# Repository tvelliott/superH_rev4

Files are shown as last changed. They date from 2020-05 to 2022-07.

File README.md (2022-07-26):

<html>
<b>High-performance narrow-band receiver hardware.</b>
<BR>
<BR><B>SuperH_rev4</B>
<BR>
<p>
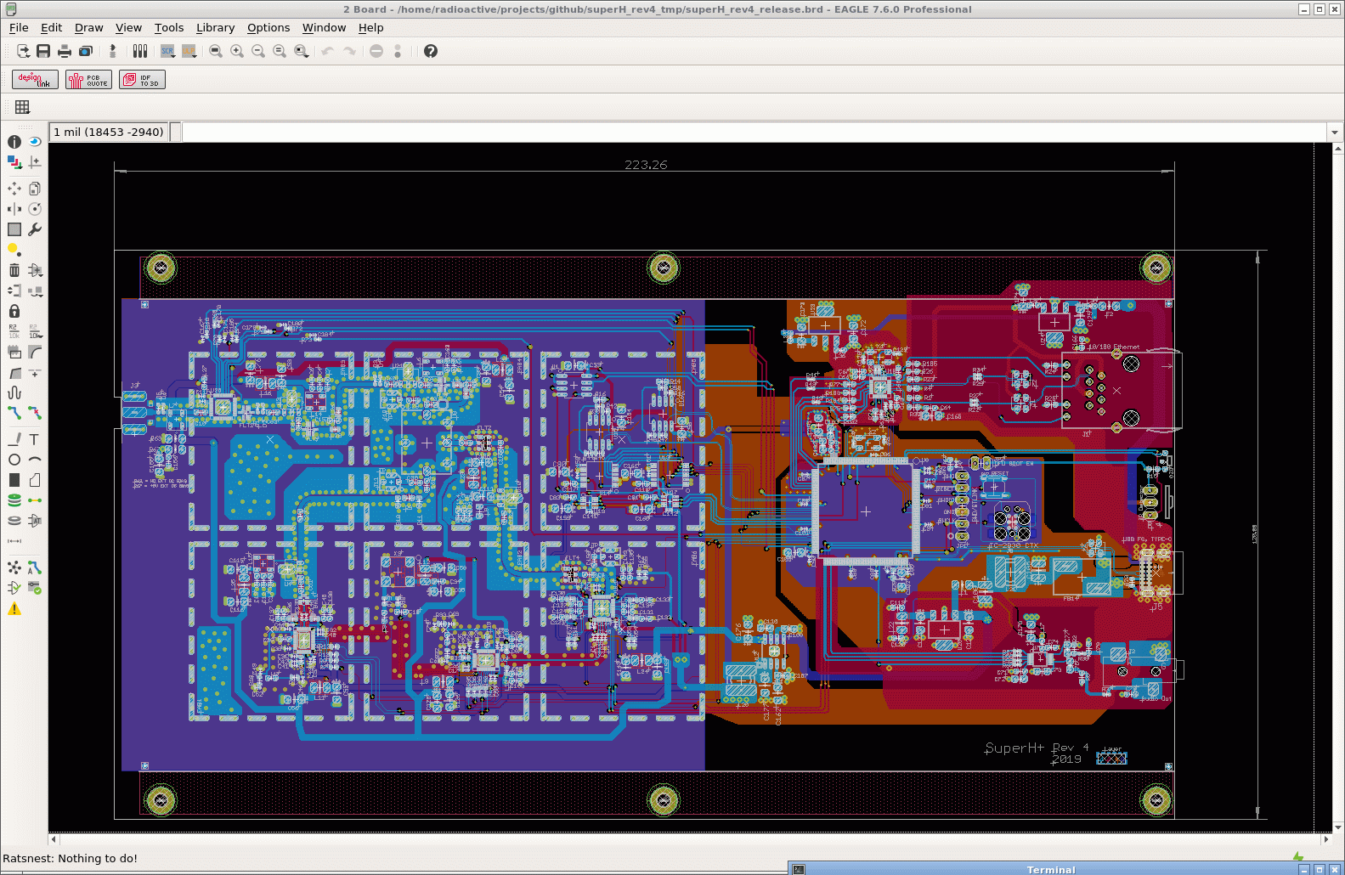
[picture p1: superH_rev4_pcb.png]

<BR>
<BR>
<BR>

<BR>To compile:
<BR>install the gcc arm toolchain version gcc-arm-none-eabi-7-2018-q2-update/
<BR>https://developer.arm.com/tools-and-software/open-source-software/developer-tools/gnu-toolchain/gnu-rm/downloads/7-2018-q2-update
<BR>
<BR>In the firmware directory, create a symbolic link to the toolchain:
<BR>e.g. ln -s ../gcc-arm-none-eabi-7-2018-q2-update arm-toolchain
<BR>Then type 'make' 
<BR><BR>
The firmware can decode the follow protocols in stand-alone mode (NO PC):
<PRE>
Available SuperH+ built-in/stand-alone demod/decoders
------------------
FM Analog narrow/med/wide (mode fm)
AM Analog narrow/med/wide (mode am)
IQ 16-bit over UDP (mode iq) + GNURadio Driver
P25P1 Voice + Trunking Control Channel (mode p25)
DMR Voice + ConnectPlus Trunking Control Channel (mode dmr)
ADSB Mode-S - Console output (mode adsb)   This mode uses 2 separate ADCs in single ended mode with 2 Msps / 8-bit.
ACARS - Console output (mode acars)
FLEX-4FSK-1600 - Console output (mode pagers, fm)
POCSAG 1200 - Console output (mode pagers, fm)
</PRE>
<BR>
<BR>

1st IF is 1.5 GHz  (high IF like a typical spectrum analyzer)
<BR><BR>
Baseband filters are 10 - 150 kHz in 16 steps.  70dB adjacent rejection,  100+ dB alternate rejection.
<BR><BR>NCO based final tuning.
<BR><BR>20dB pre-LNA step-attenuator front-end (controlled by AGC)
<BR><BR>AGC + DSP extends dynamic range to over 150dB.
<BR><BR>ACARS receives long messages >350 miles away with an indoor antenna and 0 bit errors.
<BR><BR>DC coupling and extremely stable TCXO makes sub-Hz demodulation with software-based DC offset correction possible
<BR><BR>I/Q ADCs SNR is >= 82 dB in 16-bit differential mode of operation (10-150 kHz baseband filter mode).   

<BR>
<BR>
<a href="https://github.com/tvelliott/superH_rev4/blob/master/audio_samples/superH_fm_radio_dynamics_silence_demo.wav">superH_fm_radio_dynamics_silence_demo.wav (recorded off air)</a>
<BR>
<BR>
superH FM demod demonstration   
https://youtu.be/HBXcUFW8yaA  
<BR><BR>
P25P1 demo
https://youtu.be/G3MCHvNcKHg
<BR><BR>
superH gqrx / 40-meter / AM demo
https://youtu.be/u9L5sJRPFiQ
<BR><BR>
Local ham radio repeater VHF
https://youtu.be/9KYXXc-55yA
<BR><BR>
SuperH+ receiving ADSB
https://youtu.be/LvIR2hlR7_A
<BR><BR>
<BR>
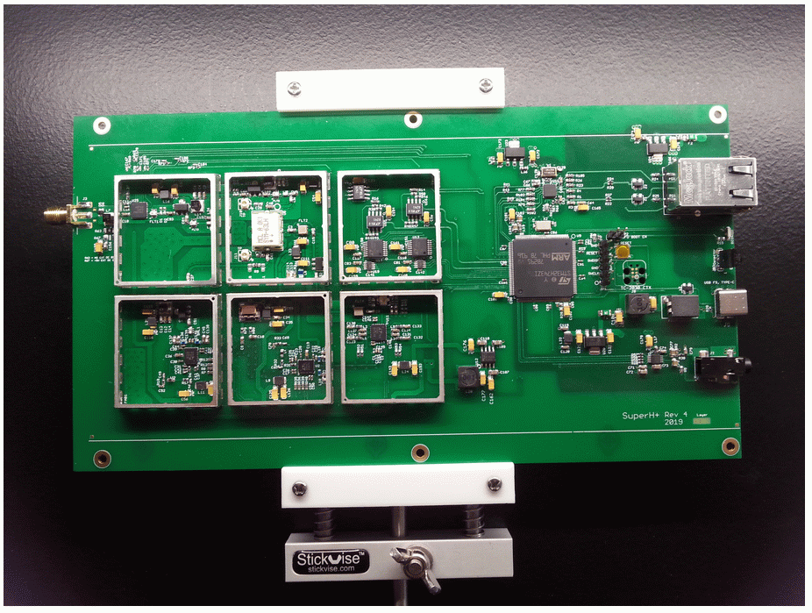
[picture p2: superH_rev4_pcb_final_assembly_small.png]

<BR>
</html>

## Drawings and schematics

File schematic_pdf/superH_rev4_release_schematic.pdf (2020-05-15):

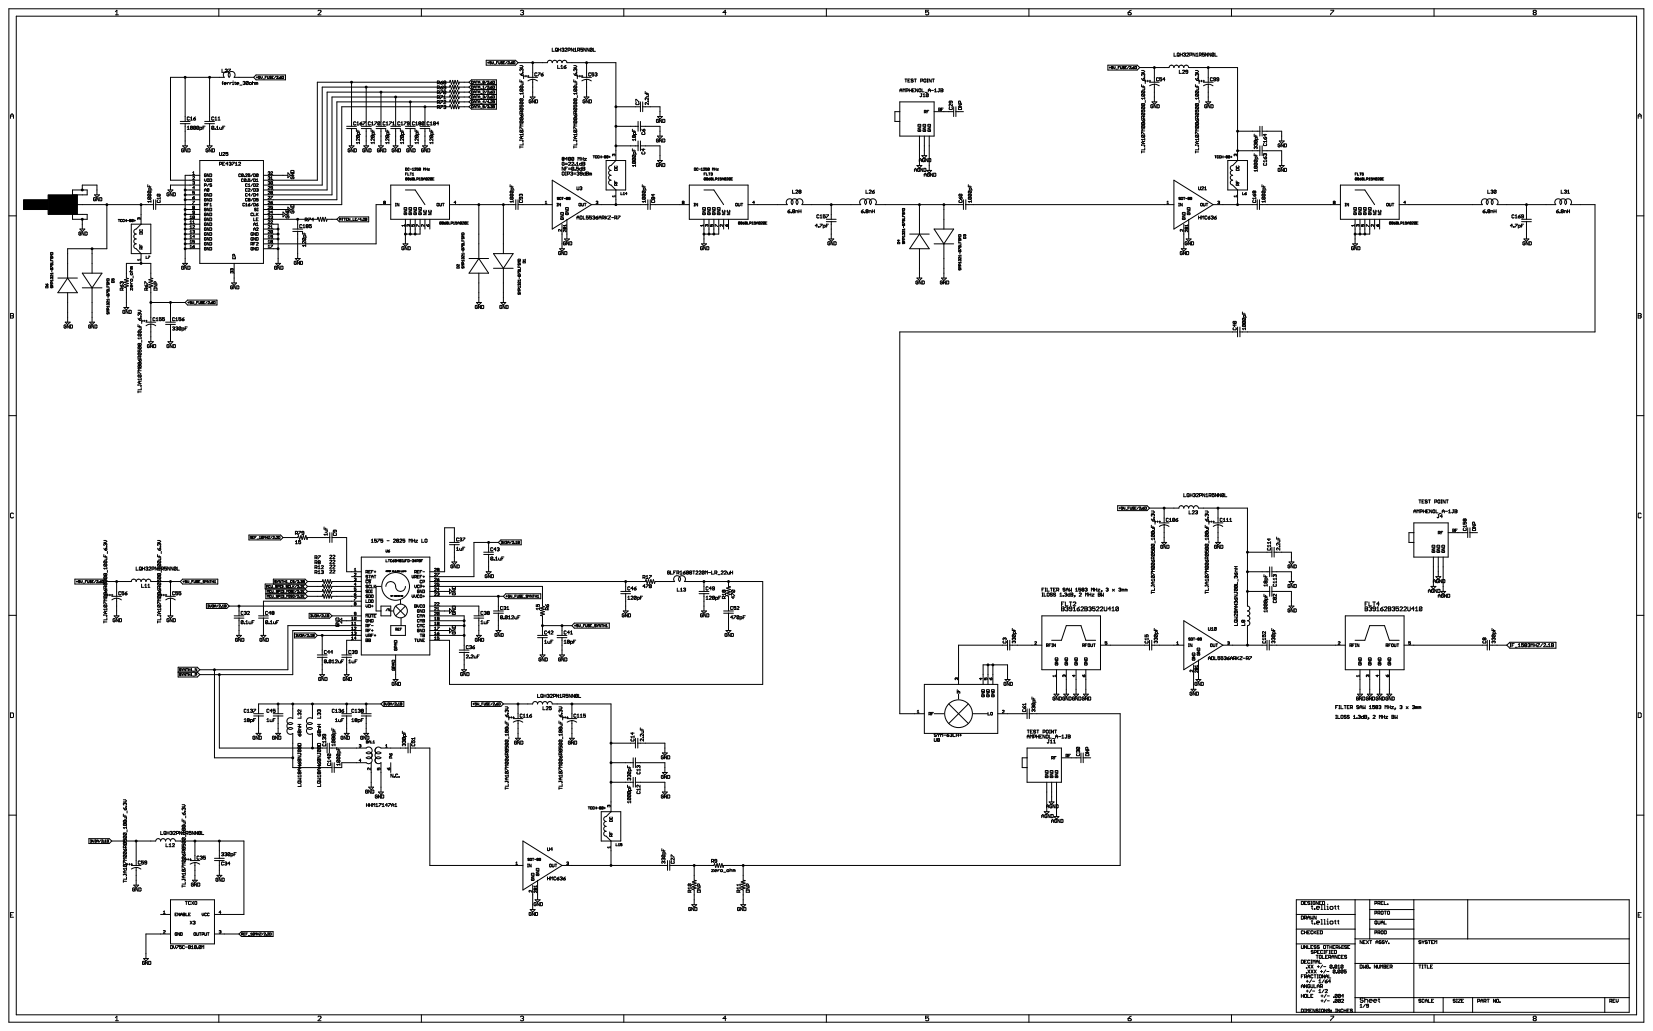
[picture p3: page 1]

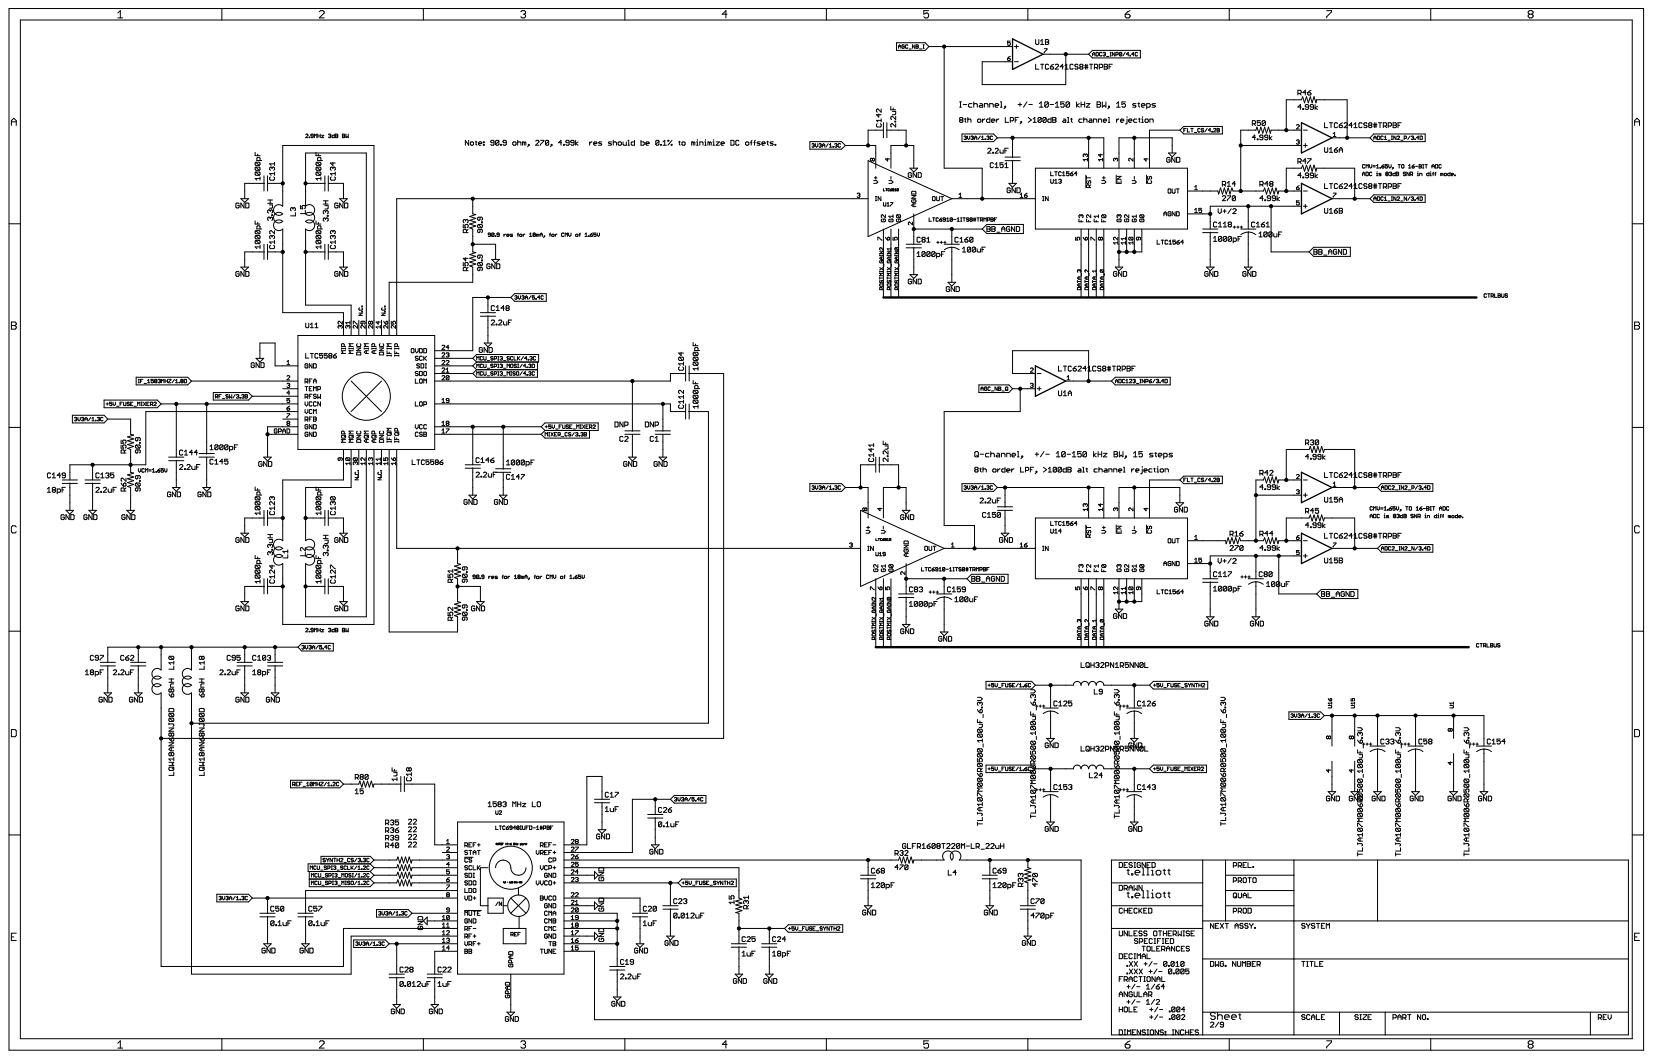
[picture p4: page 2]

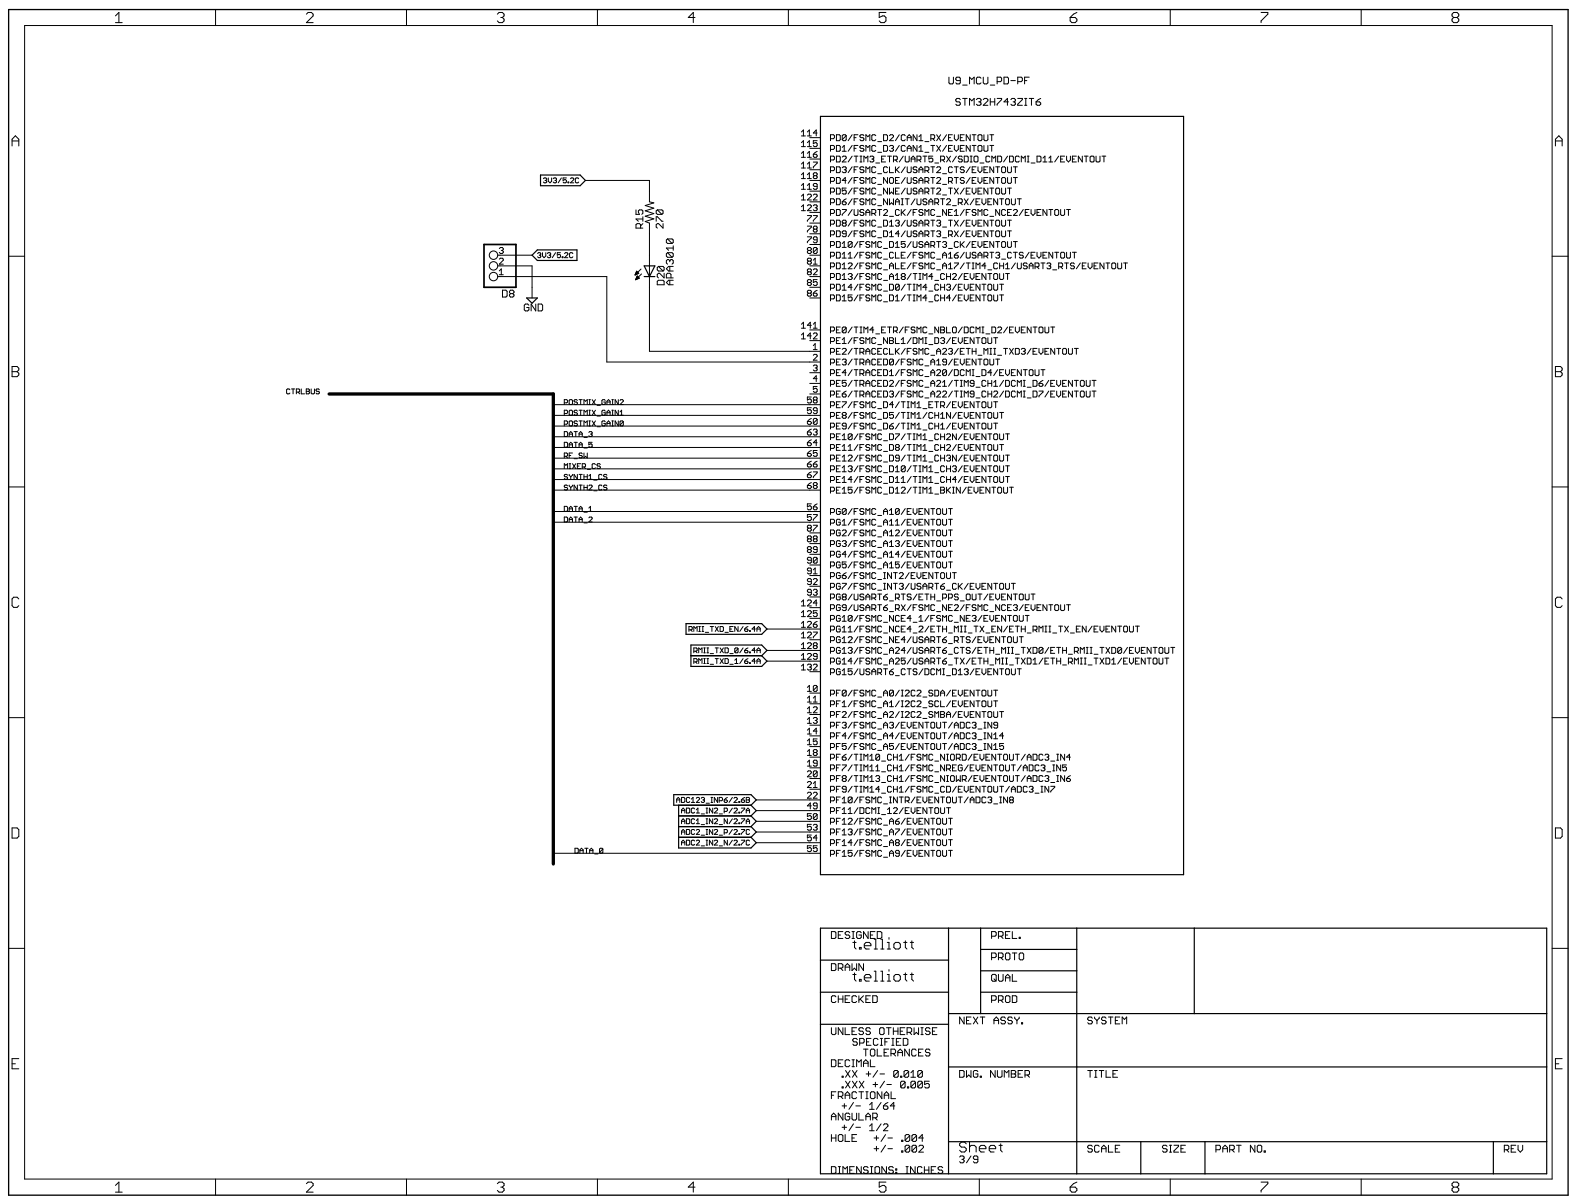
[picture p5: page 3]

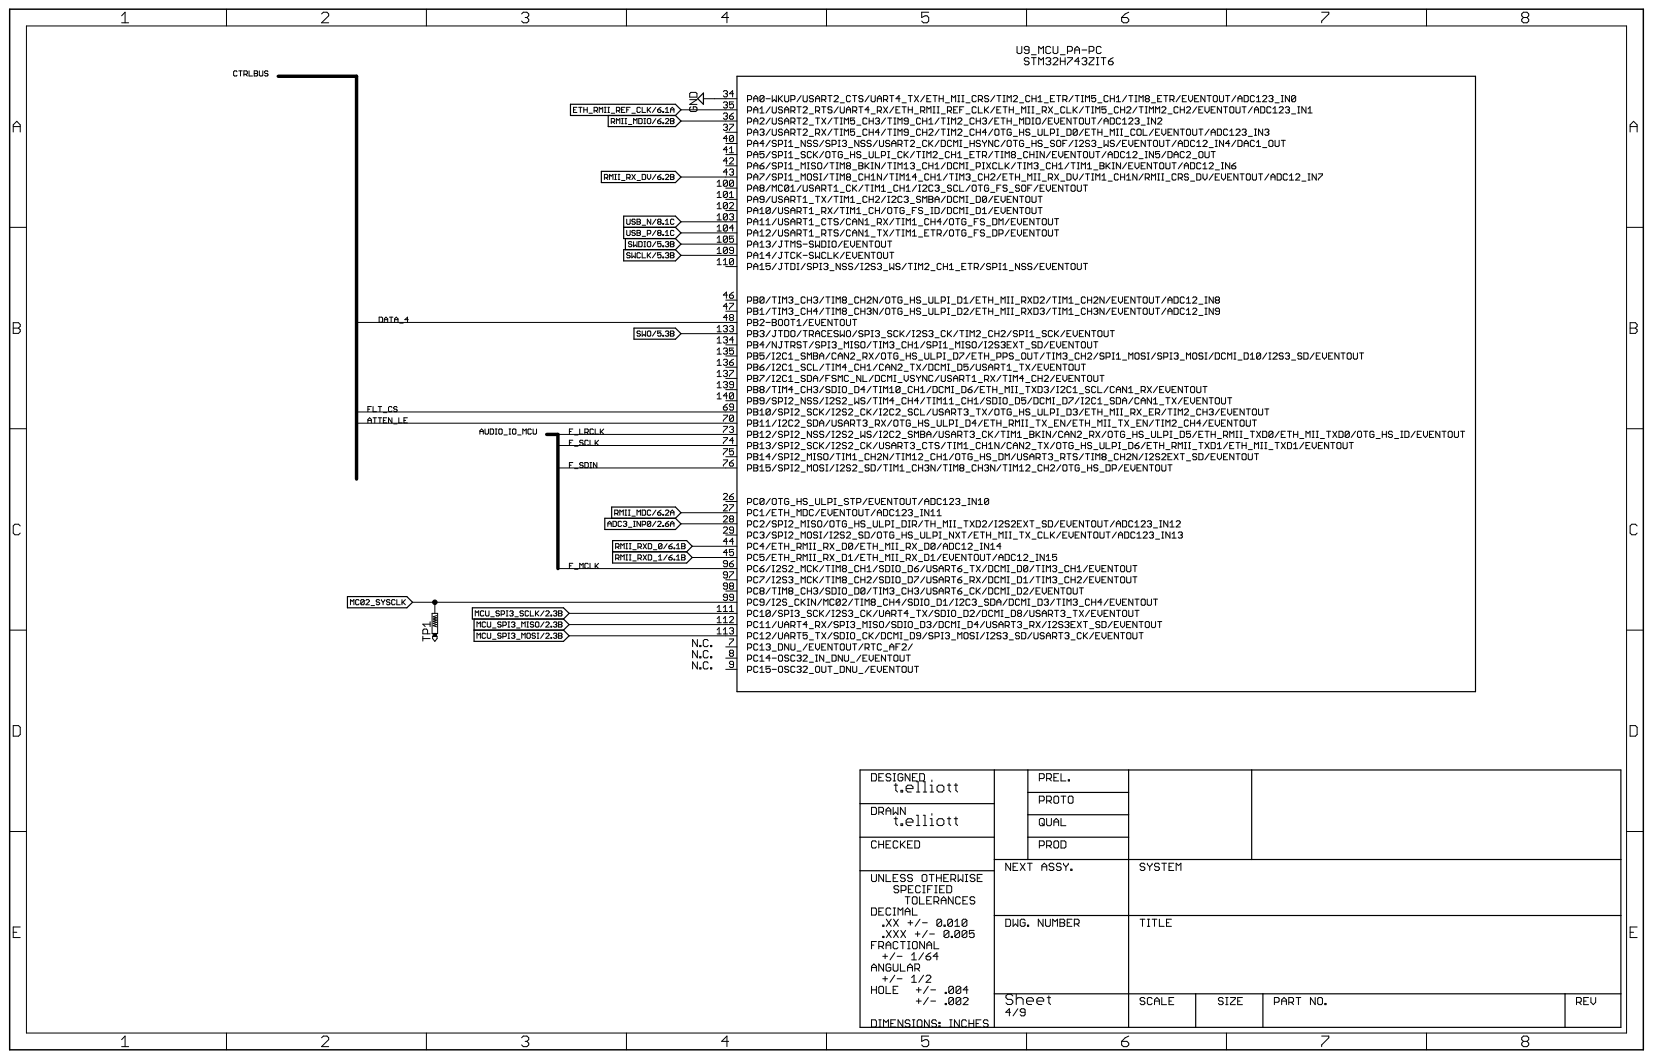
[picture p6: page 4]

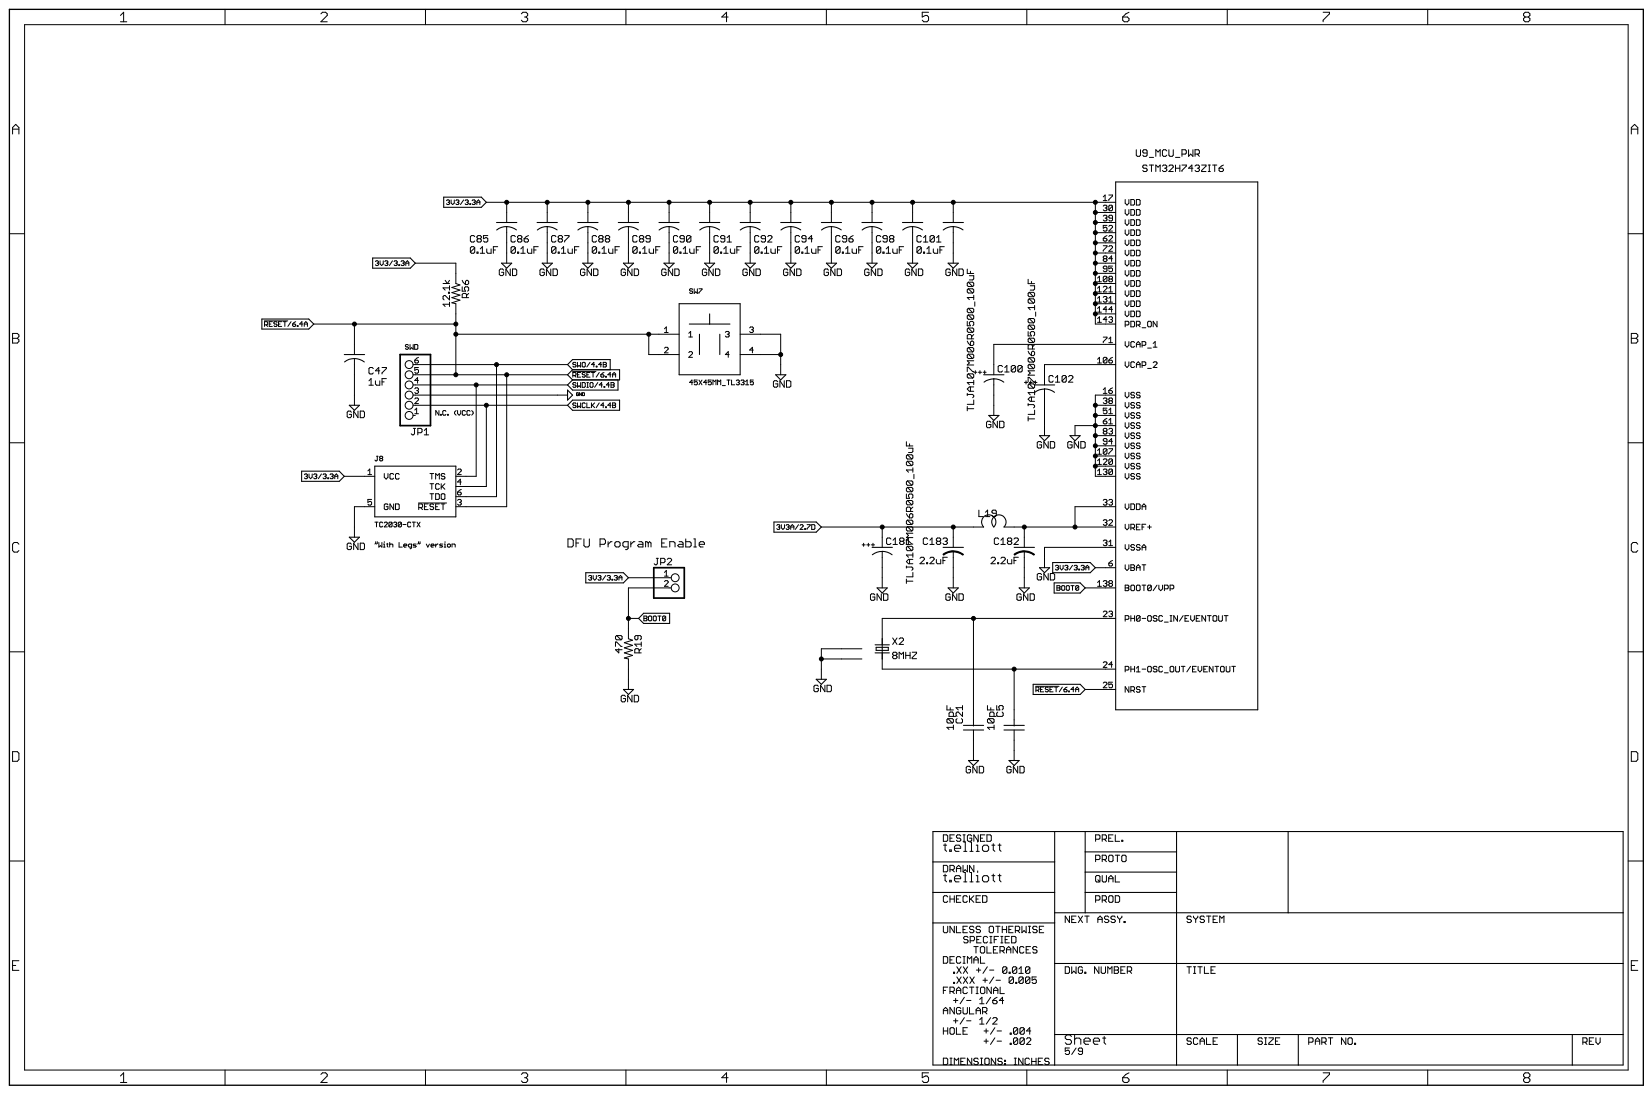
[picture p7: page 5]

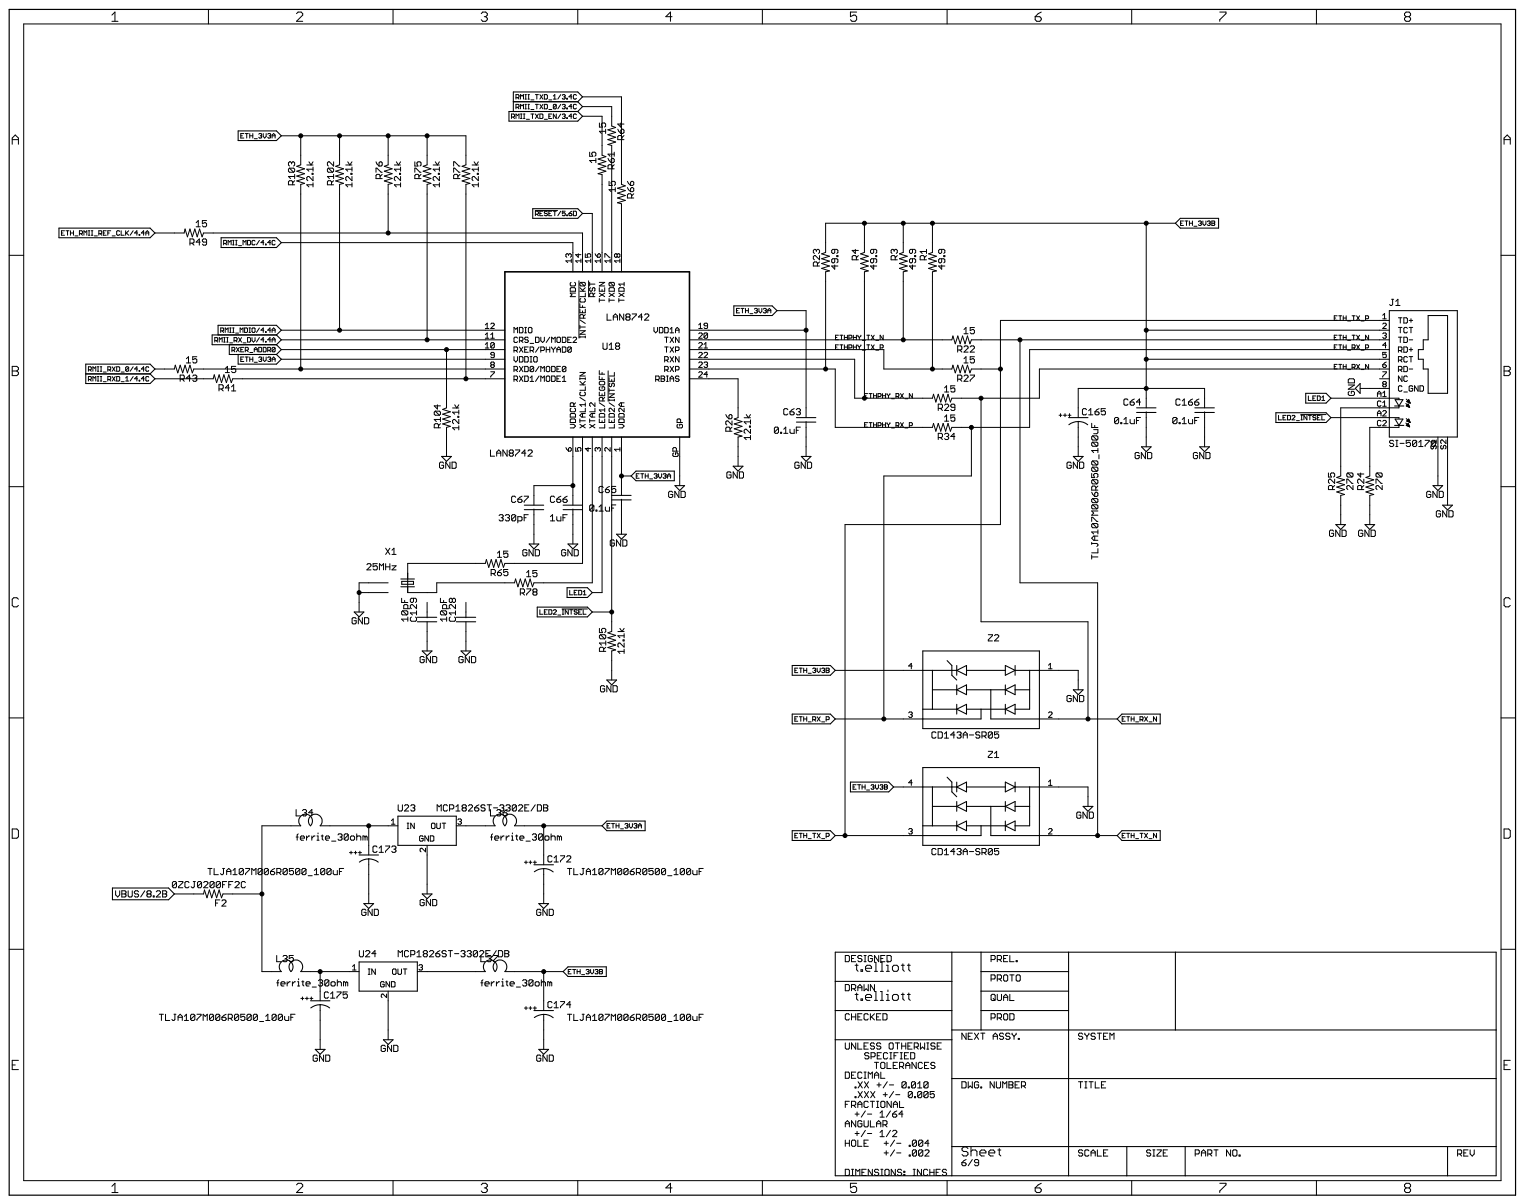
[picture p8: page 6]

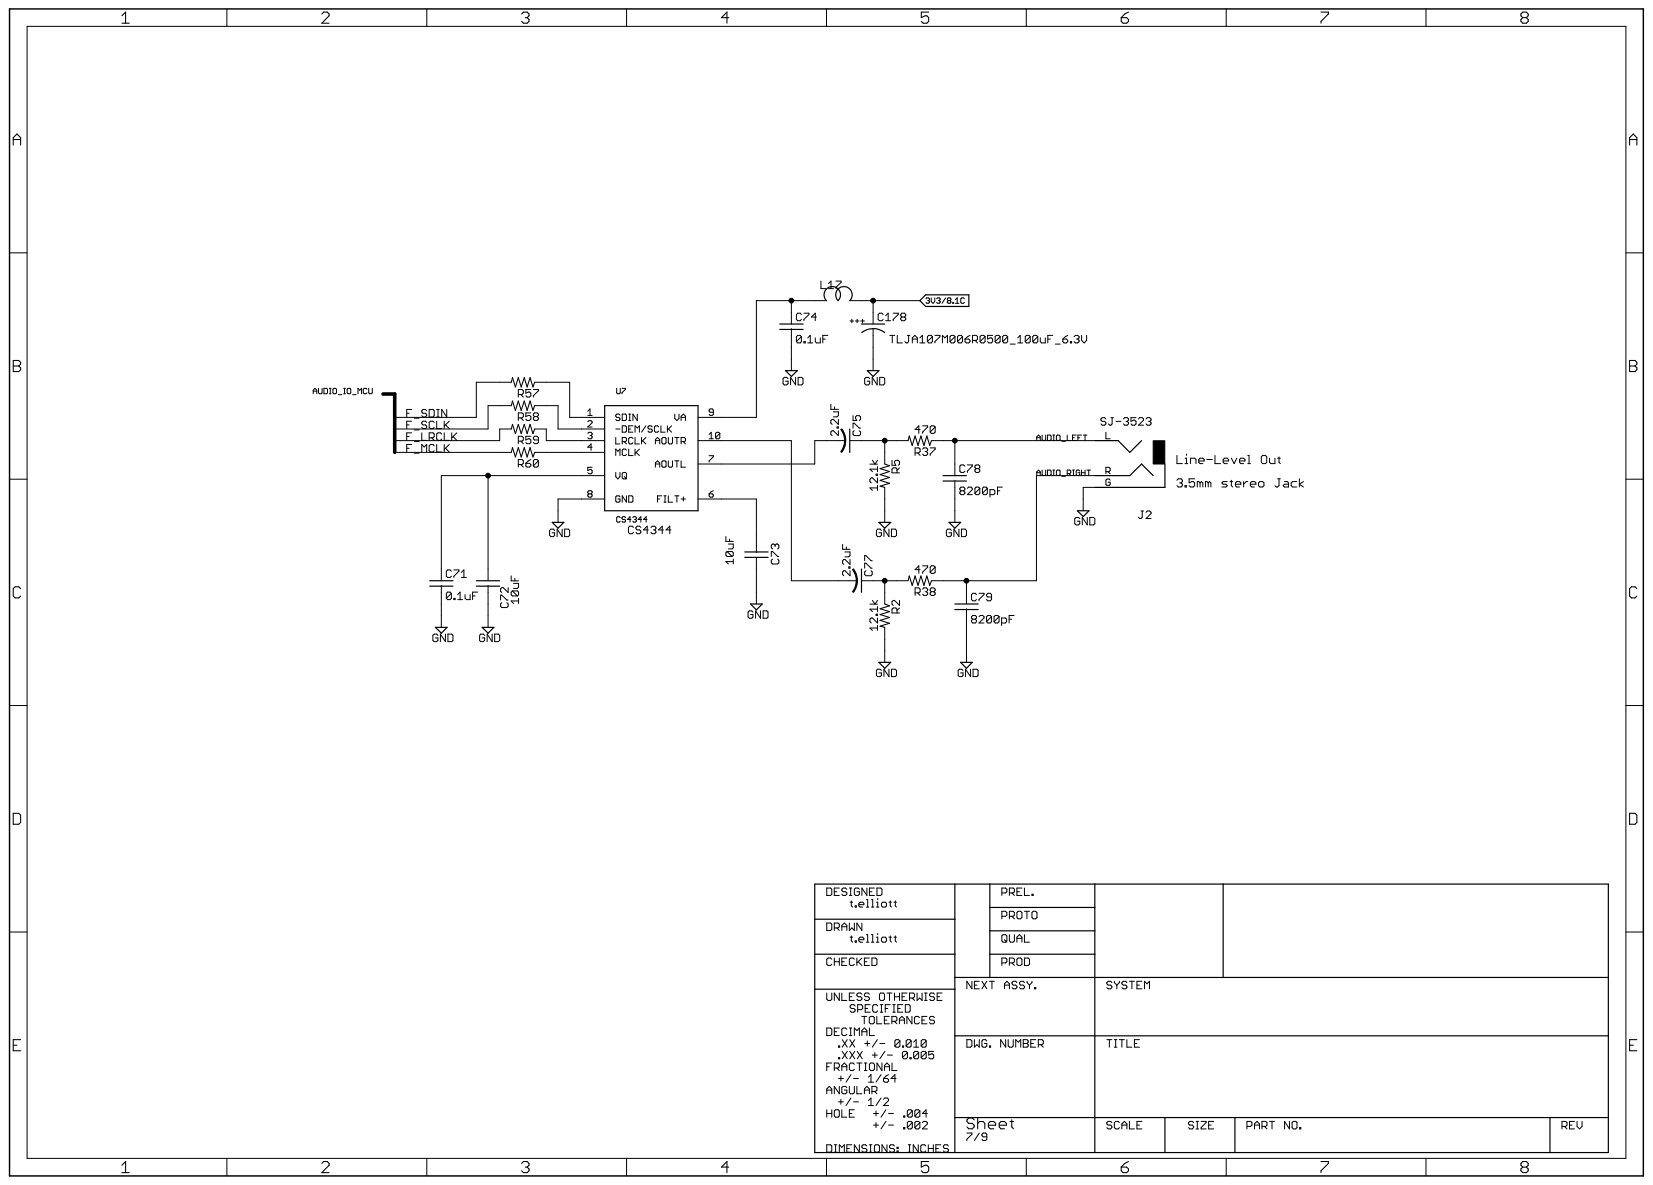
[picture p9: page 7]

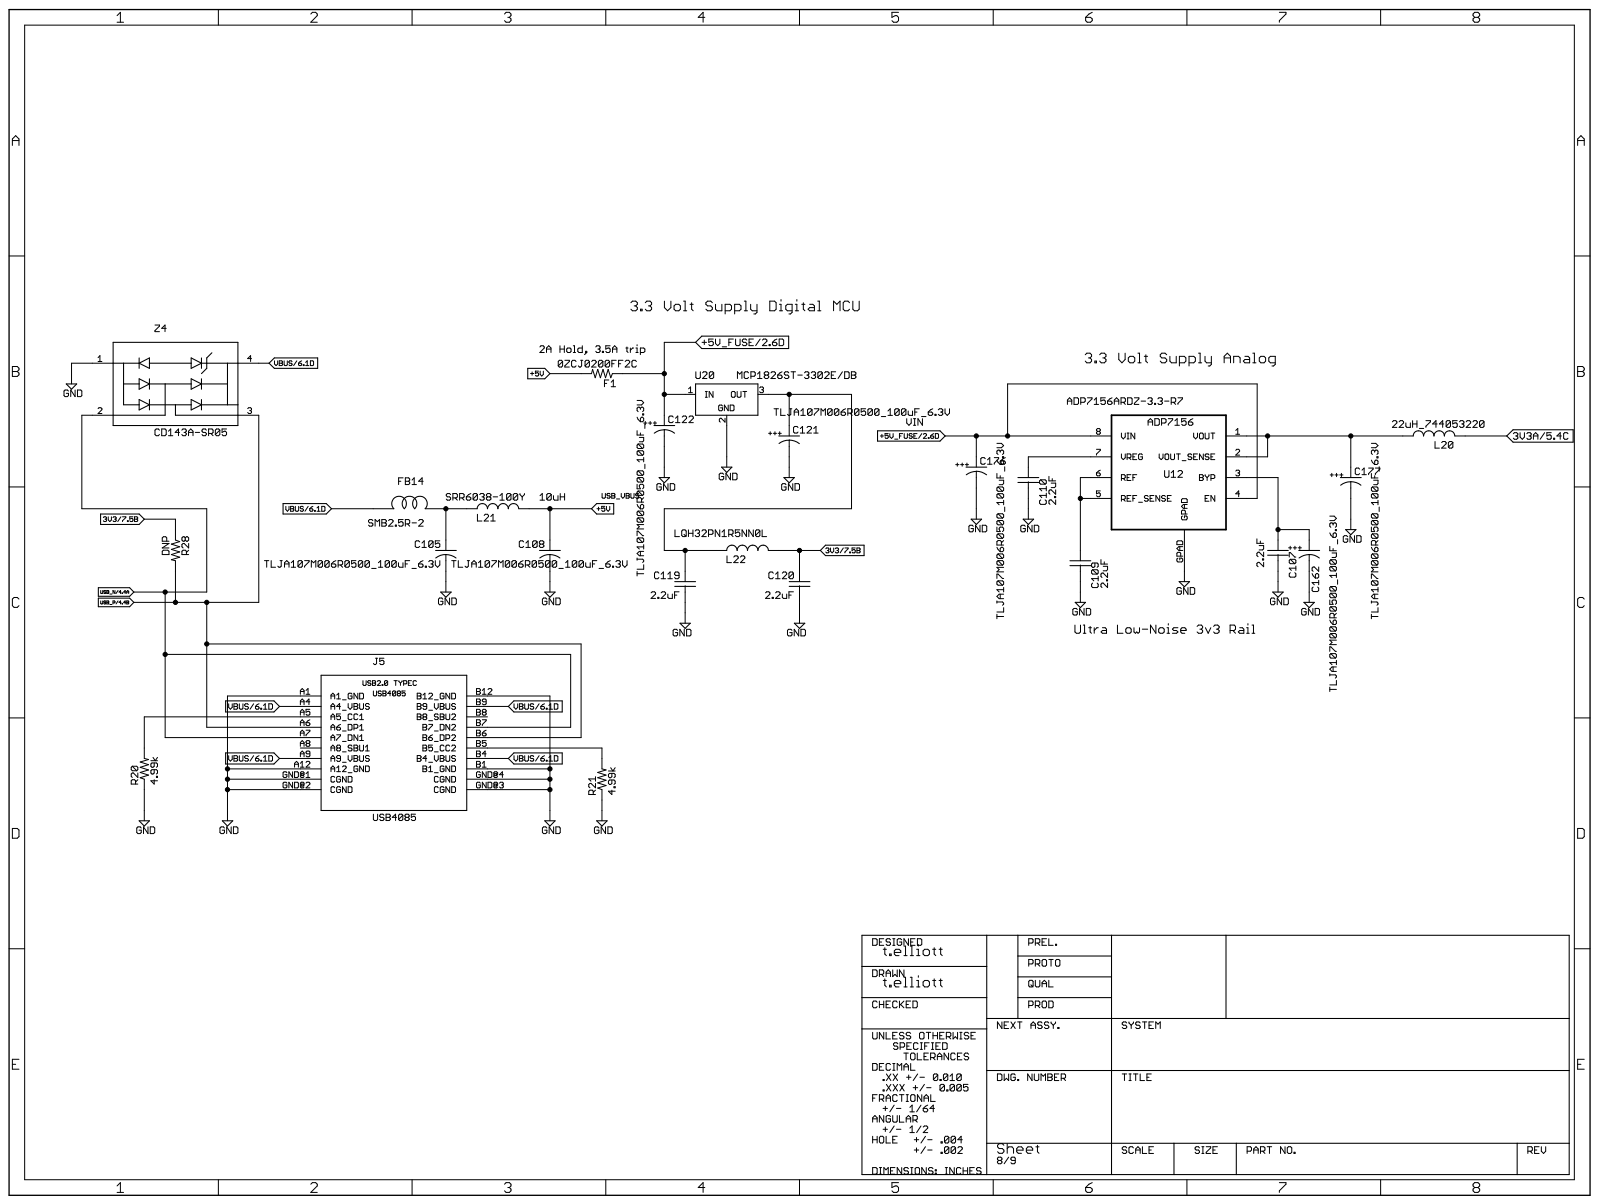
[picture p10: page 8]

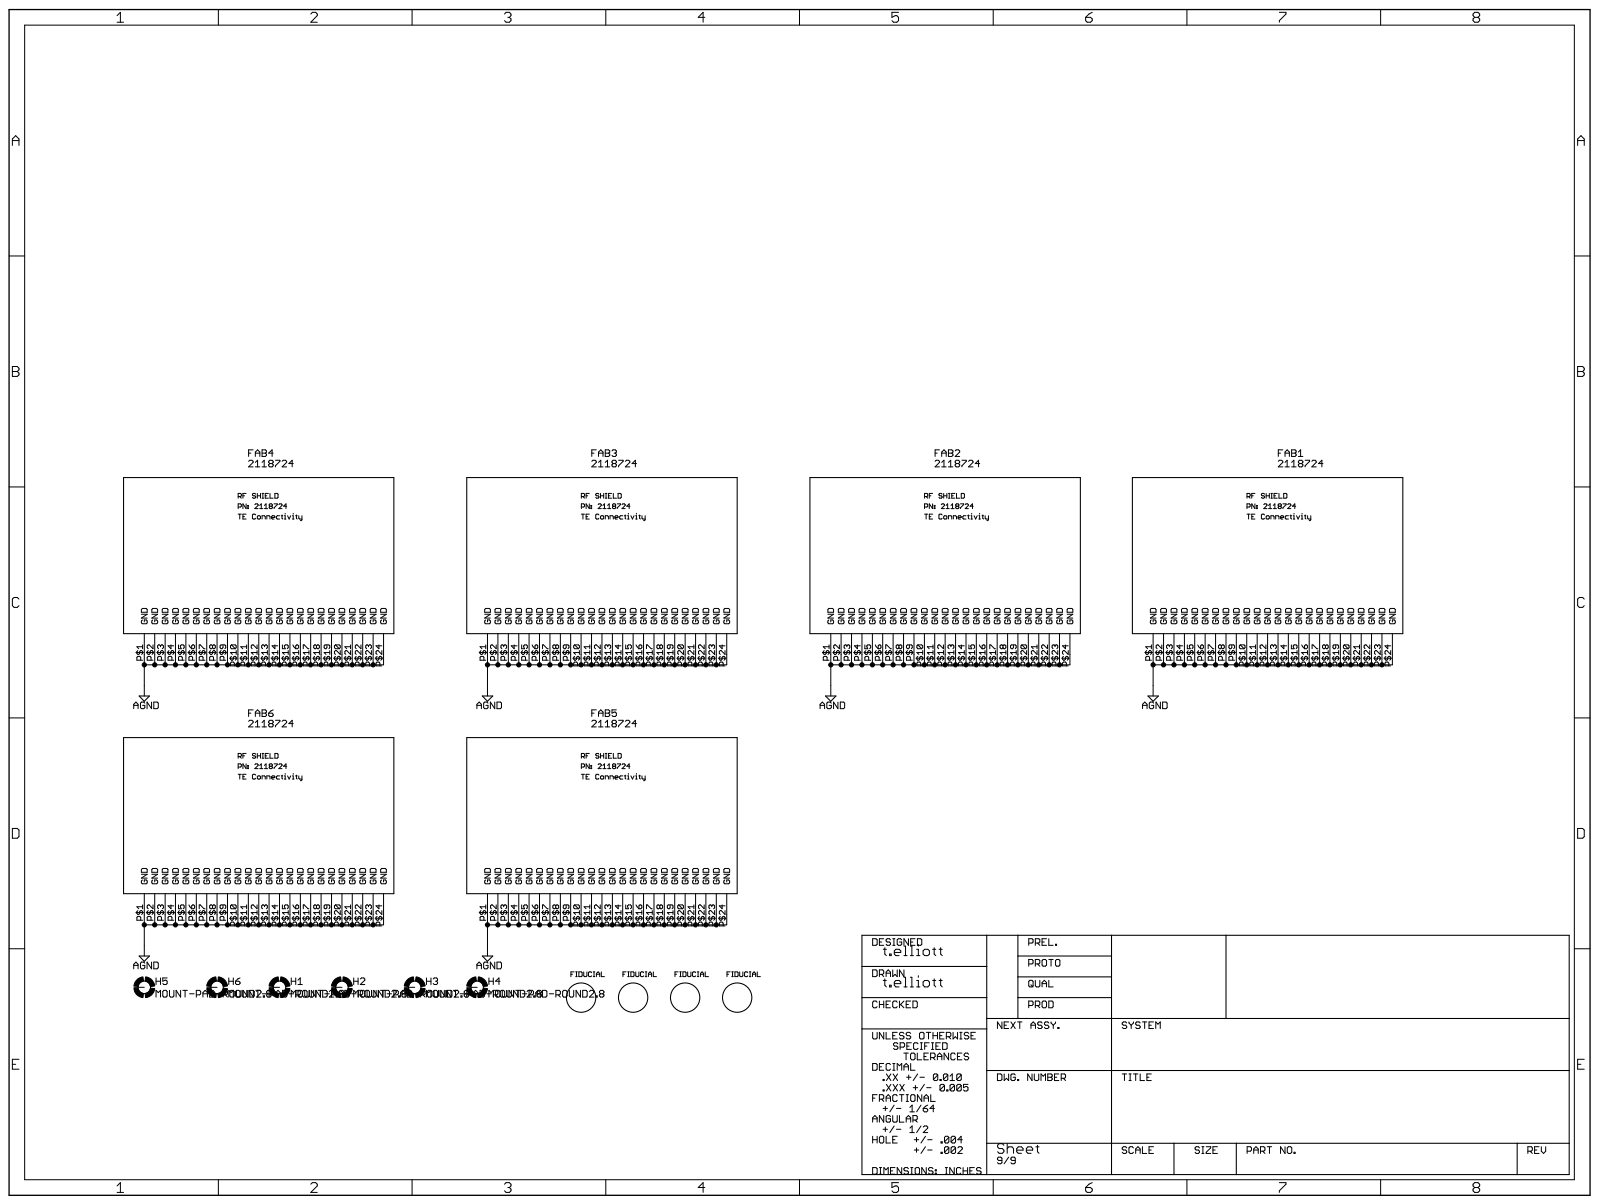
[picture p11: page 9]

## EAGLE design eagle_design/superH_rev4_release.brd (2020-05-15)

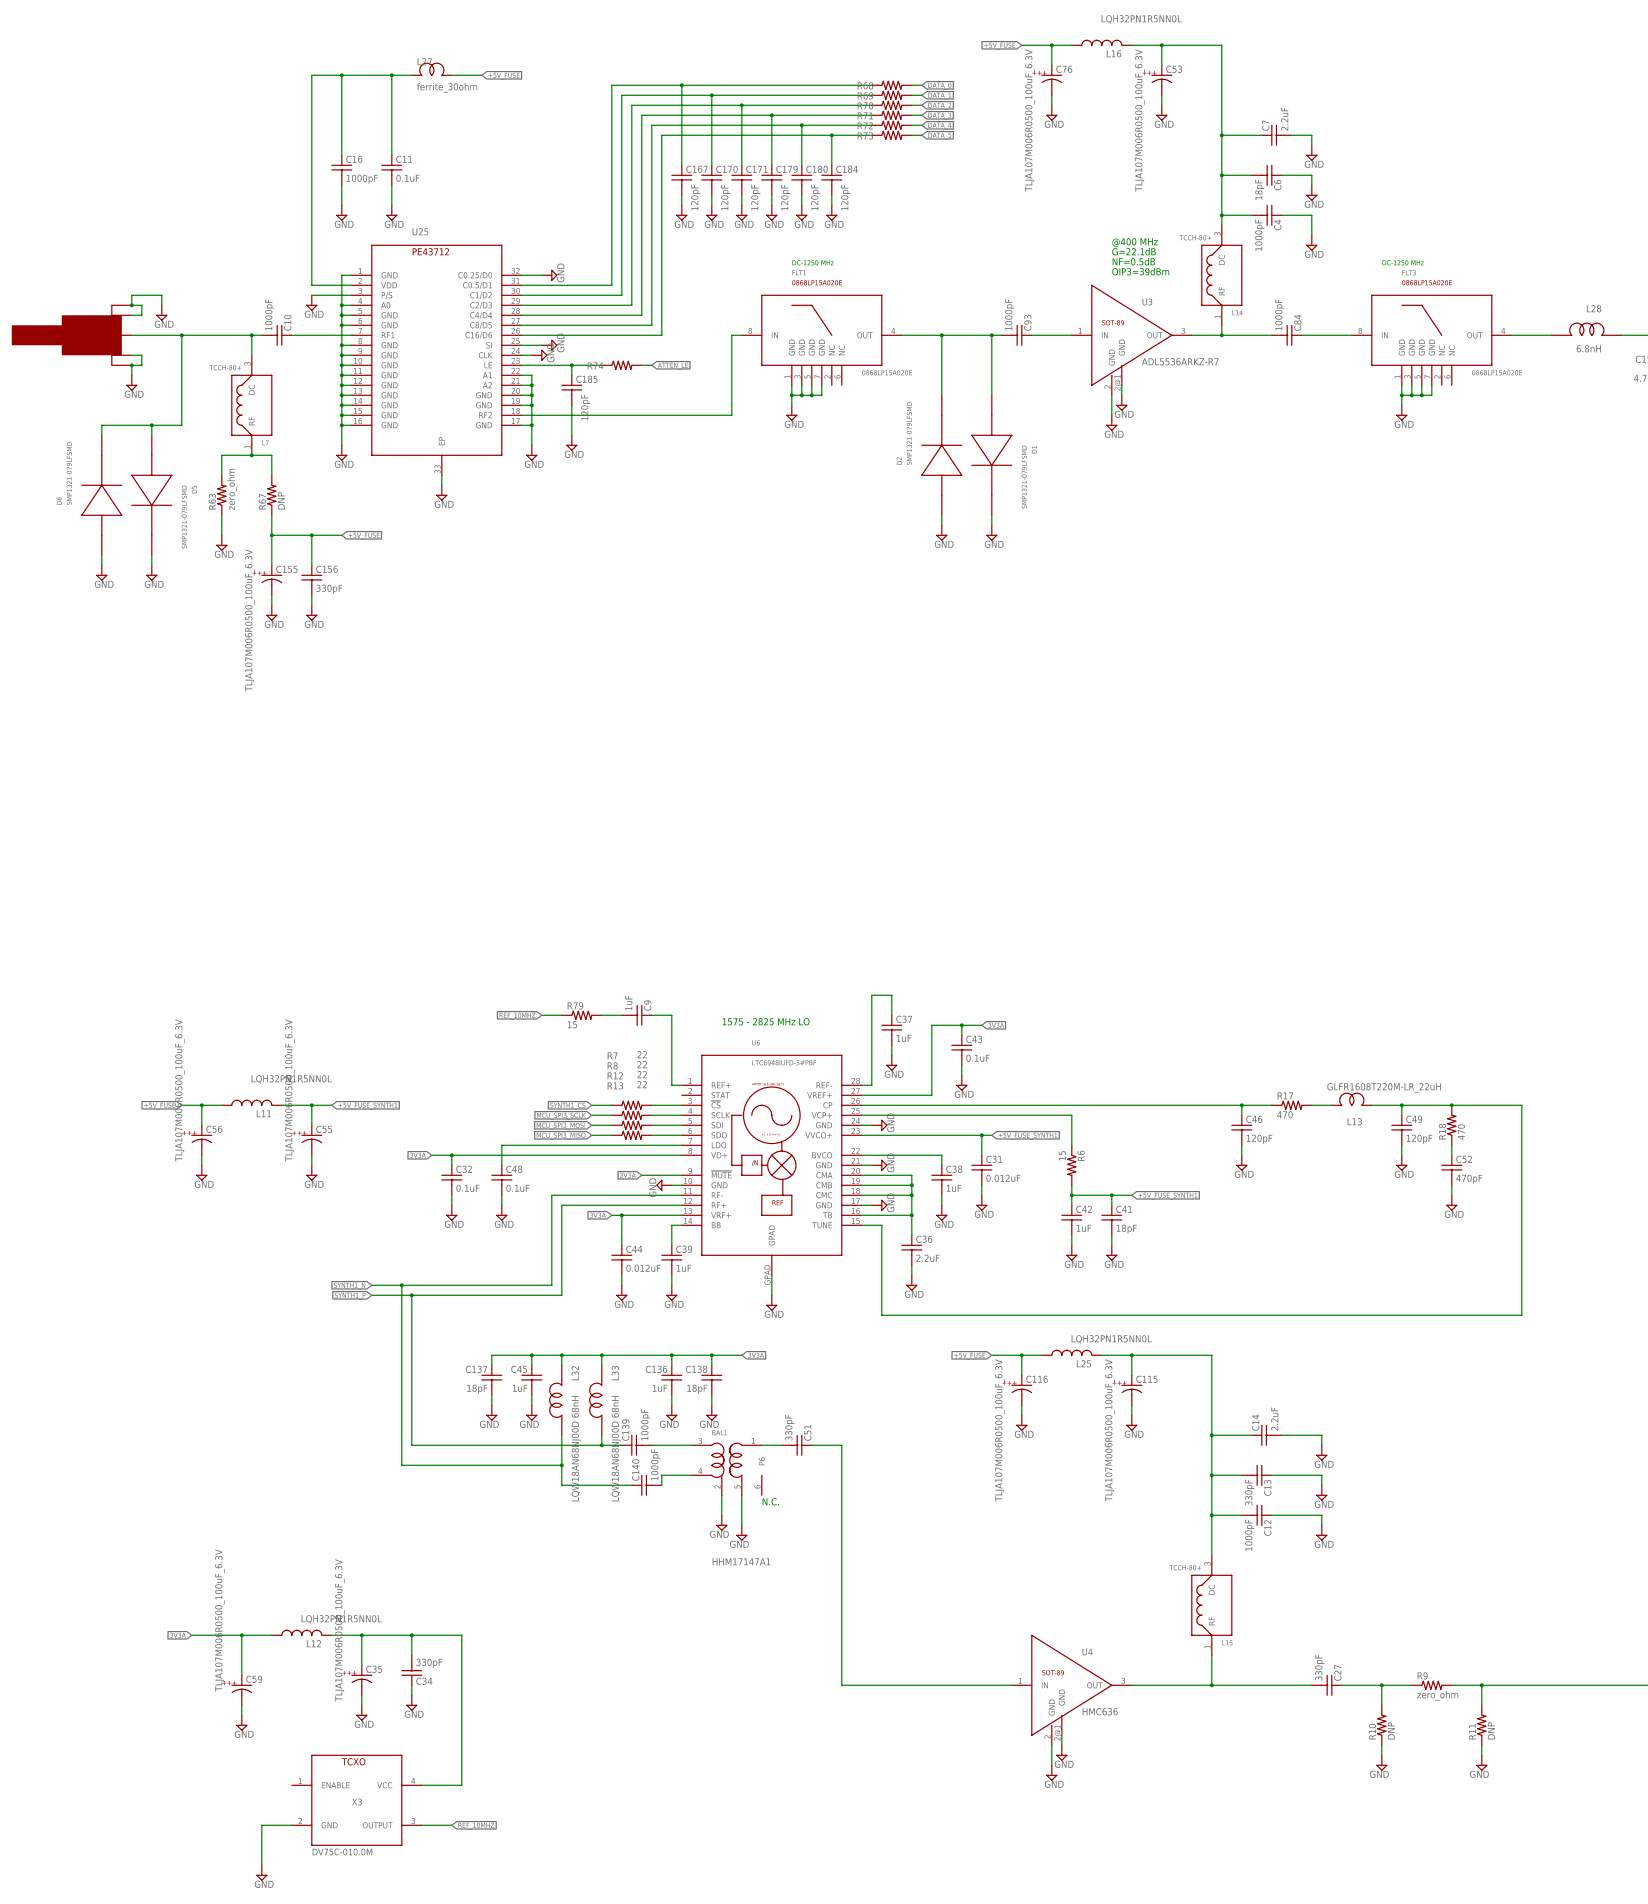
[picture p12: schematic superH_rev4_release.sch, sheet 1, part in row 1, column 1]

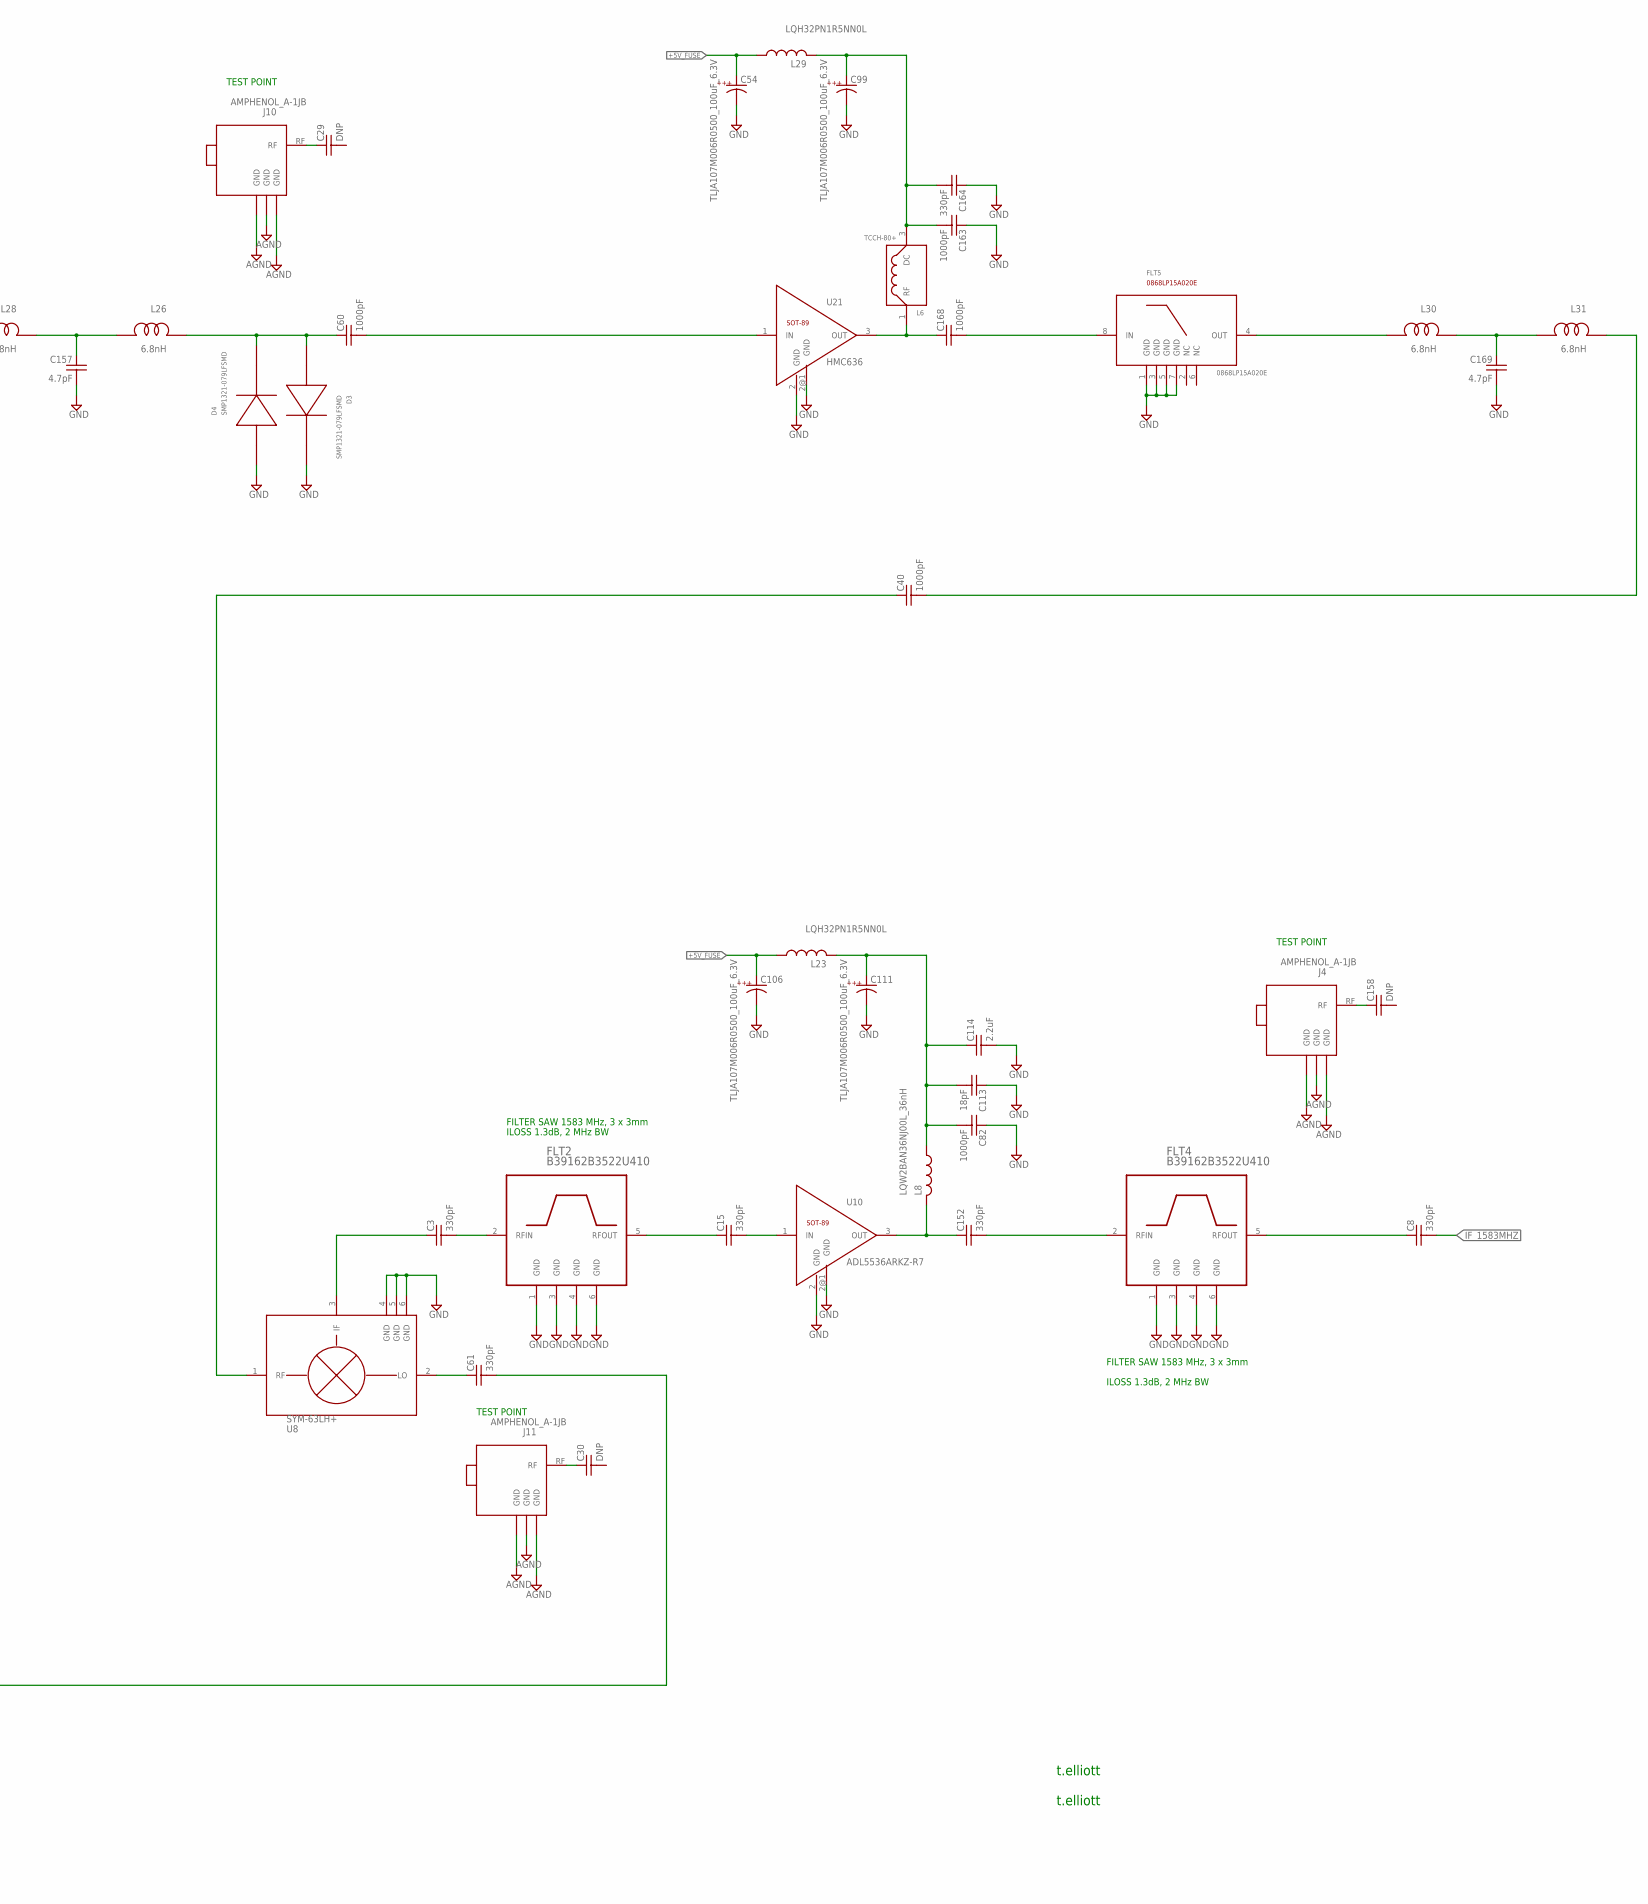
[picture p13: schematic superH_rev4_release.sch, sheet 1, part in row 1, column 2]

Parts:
BAL1: HHM17147A1; TDK_BALUN_5PIN
C3, C8, C13, C15, C27, C34, C51, C61, C152, C156, C164: 330pF; C0603
C4, C10, C12, C40, C60, C82, C84, C93, C163, C168: 1000pF; C0603
C6, C113, C137, C138: 18pF; C0603
C7, C14, C36, C114: 2.2uF; C0603
C9, C45, C136: 1uF; C0603
C11, C32, C43, C48: 0.1uF; C0402
C16, C139, C140: 1000pF; C0402
C29, C30, C158: DNP; C0603
C31, C44: 0.012uF; C0402
C35, C53, C54, C55, C56, C59, C76, C99, C106, C111, C115, C116, C155: TLJA107M006R0500_100uF_6.3V; 1210K
C37, C38, C39, C42: 1uF; C0402
C41: 18pF; C0402
C46, C49, C167, C170, C171, C179, C180, C184, C185: 120pF; C0402
C52: 470pF; C0402
C157, C169: 4.7pF; C0603
D1, D2, D3, D4, D5, D6: SMP1321-079LFSMD; SC-79_PINDIODE
FLT1, FLT3, FLT5: 0868LP15A020E; LPF_0868LP15A020
FLT2, FLT4: B39162B3522U410; SM3030-6
J3: SMA0.062; SMA_EDGE
J4, J10, J11: AMPHENOL_A-1JB; UFLCONNECTOR
L6, L7, L14, L15: TCCH-80+
L8: LQW2BAN36NJ00L_36nH; L2012C; PARTNUMBER ELJ-PA331KF
L11, L12, L16, L23, L25, L29: LQH32PN1R5NN0L; L3225M; PARTNUMBER ELJ-PA331KF
L13: GLFR1608T220M-LR_22uH; 0603
L26, L28, L30, L31: 6.8nH; MURATA_LQW_0603
L27: ferrite_30ohm; 0603
L32, L33: LQW18AN68NJ00D 68nH; MURATA_LQW_0603
R6, R68, R69, R70, R71, R72, R73, R74, R79: 15; R0402
R7, R8, R12, R13: 22; R0603_COMPACT
R9: zero_ohm; R0603
R10, R11: DNP; R0603
R17, R18: 470; R0402
R63: zero_ohm; R1206
R67: DNP; R1206
U3, U10: ADL5536ARKZ-R7; SOT89
U4, U21: HMC636; SOT89
U6: LTC6948IUFD-3#PBF; QFN28_NONSQ
U8: SYM-63LH+; SYM-18H
U25: PE43712SMD; QFN32
X3: DV75C-010.0M; CWX8XX_5MM_7MM

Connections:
3V3A: C32.1, C43.1, C44.1, C45.1, C59.A, C136.1, C137.1, C138.1, L12.1, L32.2, L33.2, U6.8 (VD+), U6.9 (!MUTE), U6.13 (VRF+), U6.27 (VREF+); also elsewhere on the board
+5V_ATTEN: C11.1, C16.1, L27.1, U25.2 (VDD)
+5V_FUSE: C54.A, C56.A, C76.A, C106.A, C116.A, C155.A, C156.1, L11.1, L16.1, L23.1, L25.1, L27.2, L29.1, R67.1; also elsewhere on the board
+5V_FUSE_SYNTH1: C31.1, C41.1, C42.1, C55.A, L11.2, R6.2, U6.23 (VVCO+)
ATTEN_LE: R74.2; also elsewhere on the board
BALUN_N: BAL1.4 (BP1), C140.2
BALUN_P: BAL1.3 (BP2), C139.2
D0: C167.1, R68.1, U25.31 (C0.5/D1)
D1: C170.1, R69.1, U25.30 (C1/D2)
D2: C171.1, R70.1, U25.29 (C2/D3)
D3: C179.1, R71.1, U25.28 (C4/D4)
D4: C180.1, R72.1, U25.27 (C8/D5)
D5: C184.1, R73.1, U25.26 (C16/D6)
DATA_0: R68.2; also elsewhere on the board
DATA_1: R69.2; also elsewhere on the board
DATA_2: R70.2; also elsewhere on the board
DATA_3: R71.2; also elsewhere on the board
DATA_4: R72.2; also elsewhere on the board
DATA_5: R73.2; also elsewhere on the board
GND: BAL1.2 (FEED), BAL1.5 (GND), C4.1, C6.1, C7.2, C11.2, C12.1, C13.1, C14.2, C16.2, C31.2, C32.2, C34.1, C35.C, C36.2, C37.2, C38.2, C39.2, C41.2, C42.2, C43.2, C44.2, C45.2, C46.2, C48.2, C49.2, C52.2, C53.C, C54.C, C55.C, C56.C, C59.C, C76.C, C82.1, C99.C, C106.C, C111.C, C113.1, C114.2, C115.C, C116.C, C136.2, C137.2, C138.2, C155.C, C156.2, C157.2, C163.1, C164.1, C167.2, C169.2, C170.2, C171.2, C179.2, C180.2, C184.2, C185.2, D1.C, D2.A, D3.C, D4.A, D5.C, D6.A, FLT1.1 (GND), FLT1.3 (GND), FLT1.5 (GND), FLT1.7 (GND), FLT2.1 (GND), FLT2.3 (GND), FLT2.4 (GND), FLT2.6 (GND), FLT3.1 (GND), FLT3.3 (GND), FLT3.5 (GND), FLT3.7 (GND), FLT4.1 (GND), FLT4.3 (GND), FLT4.4 (GND), FLT4.6 (GND), FLT5.1 (GND), FLT5.3 (GND), FLT5.5 (GND), FLT5.7 (GND), J3.GND@1 (GND), J3.GND@2 (GND), J3.GND@3 (GND), J3.GND@4 (GND), J4.1 (GND), J4.2 (GND), J4.3 (GND), J10.1 (GND), J10.2 (GND), J10.3 (GND), J11.1 (GND), J11.2 (GND), J11.3 (GND), R10.1, R11.1, R63.1, U3.2 (GND), U3.2@1 (GND), U4.2 (GND), U4.2@1 (GND), U6.10 (GND), U6.17 (GND), U6.21 (GND), U6.24 (GND), U6.GPAD, U8.4 (GND), U8.5 (GND), U8.6 (GND), U10.2 (GND), U10.2@1 (GND), U21.2 (GND), U21.2@1 (GND), U25.1 (GND), U25.3 (P/S), U25.4 (A0), U25.5 (GND), U25.6 (GND), U25.8 (GND), U25.9 (GND), U25.10 (GND), U25.11 (GND), U25.12 (GND), U25.13 (GND), U25.14 (GND), U25.15 (GND), U25.16 (GND), U25.17 (GND), U25.19 (GND), U25.20 (GND), U25.21 (A2), U25.22 (A1), U25.24 (CLK), U25.25 (SI), U25.32 (C0.25/D0), U25.33 (EP), X3.2 (GND); also elsewhere on the board
IF_1583MHZ: C8.2; also elsewhere on the board
LE: C185.1, R74.1, U25.23 (LE)
MCU_SPI3_MISO: R13.1; also elsewhere on the board
MCU_SPI3_MOSI: R12.1; also elsewhere on the board
MCU_SPI3_SCLK: R8.1; also elsewhere on the board
unnamed: C152.2, FLT4.2 (RFIN)
unnamed: C84.2, L14.1 (RF), U3.3 (OUT)
unnamed: C82.2, C111.A, C113.2, C114.1, L8.1, L23.2
unnamed: C60.1, D3.A, D4.C, L26.2
unnamed: C27.2, L15.1 (RF), U4.3 (OUT)
unnamed: C29.1, J10.RF
unnamed: C30.1, J11.RF
unnamed: C15.1, FLT2.5 (RFOUT)
unnamed: C3.2, FLT2.2 (RFIN)
unnamed: C51.1, U4.1 (IN)
unnamed: C15.2, U10.1 (IN)
unnamed: C9.1, U6.1 (REF+)
unnamed: C27.1, R9.1, R10.2
unnamed: C61.2, R9.2, R11.2
unnamed: C4.2, C6.2, C7.1, C53.A, L14.3 (DC), L16.2
unnamed: C8.1, FLT4.5 (RFOUT)
unnamed: FLT1.8 (IN), U25.18 (RF2)
unnamed: C99.A, C163.2, C164.2, L6.3 (DC), L29.2
unnamed: C37.1, U6.28 (REF-)
unnamed: C36.1, U6.16 (TB), U6.18 (CMC), U6.19 (CMB), U6.20 (CMA)
unnamed: C38.1, U6.22 (BVCO)
unnamed: C39.1, U6.14 (BB)
unnamed: R6.1, U6.25 (VCP+)
unnamed: C48.1, U6.7 (LDO)
unnamed: C46.1, R17.1, U6.26 (CP)
unnamed: C61.1, U8.2 (LO)
unnamed: C93.1, U3.1 (IN)
unnamed: BAL1.1 (UBAL), C51.2
unnamed: C52.1, R18.1
unnamed: C49.1, L13.2, R18.2, U6.15 (TUNE)
unnamed: L13.1, R17.2
unnamed: C93.2, D1.A, D2.C, FLT1.4 (OUT)
unnamed: R7.2, U6.3 (!CS)
unnamed: R8.2, U6.4 (SCLK)
unnamed: R12.2, U6.5 (SDI)
unnamed: R13.2, U6.6 (SDO)
unnamed: C34.2, C35.A, L12.2, X3.4 (VCC)
unnamed: C3.1, U8.3 (IF)
unnamed: C157.1, L26.1, L28.2
unnamed: FLT3.4 (OUT), L28.1
unnamed: L7.1 (RF), R63.2, R67.2
unnamed: C152.1, L8.2, U10.3 (OUT)
unnamed: C84.1, FLT3.8 (IN)
unnamed: C158.1, J4.RF
unnamed: C60.2, U21.1 (IN)
unnamed: C168.1, L6.1 (RF), U21.3 (OUT)
unnamed: C40.1, U8.1 (RF)
unnamed: FLT5.4 (OUT), L30.1
unnamed: C169.1, L30.2, L31.1
unnamed: C168.2, FLT5.8 (IN)
unnamed: C40.2, L31.2
unnamed: C10.1, U25.7 (RF1)
unnamed: C10.2, D5.A, D6.C, J3.RF, L7.3 (DC)
unnamed: C9.2, R79.2
unnamed: C12.2, C13.2, C14.1, C115.A, L15.3 (DC), L25.2
REF_10MHZ: R79.1, X3.3 (OUTPUT); also elsewhere on the board
SYNTH1_CS: R7.1; also elsewhere on the board
SYNTH1_N: C140.1, L32.1, U6.11 (RF-)
SYNTH1_P: C139.1, L33.1, U6.12 (RF+)

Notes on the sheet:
t.elliott
TEST POINT
G=22.1dB
NF=0.5dB
OIP3=39dBm
FILTER SAW 1583 MHz, 3 x 3mm
N.C.
1575 - 2825 MHz LO
ILOSS 1.3dB, 2 MHz BW
DC-1250 MHz
@400 MHz

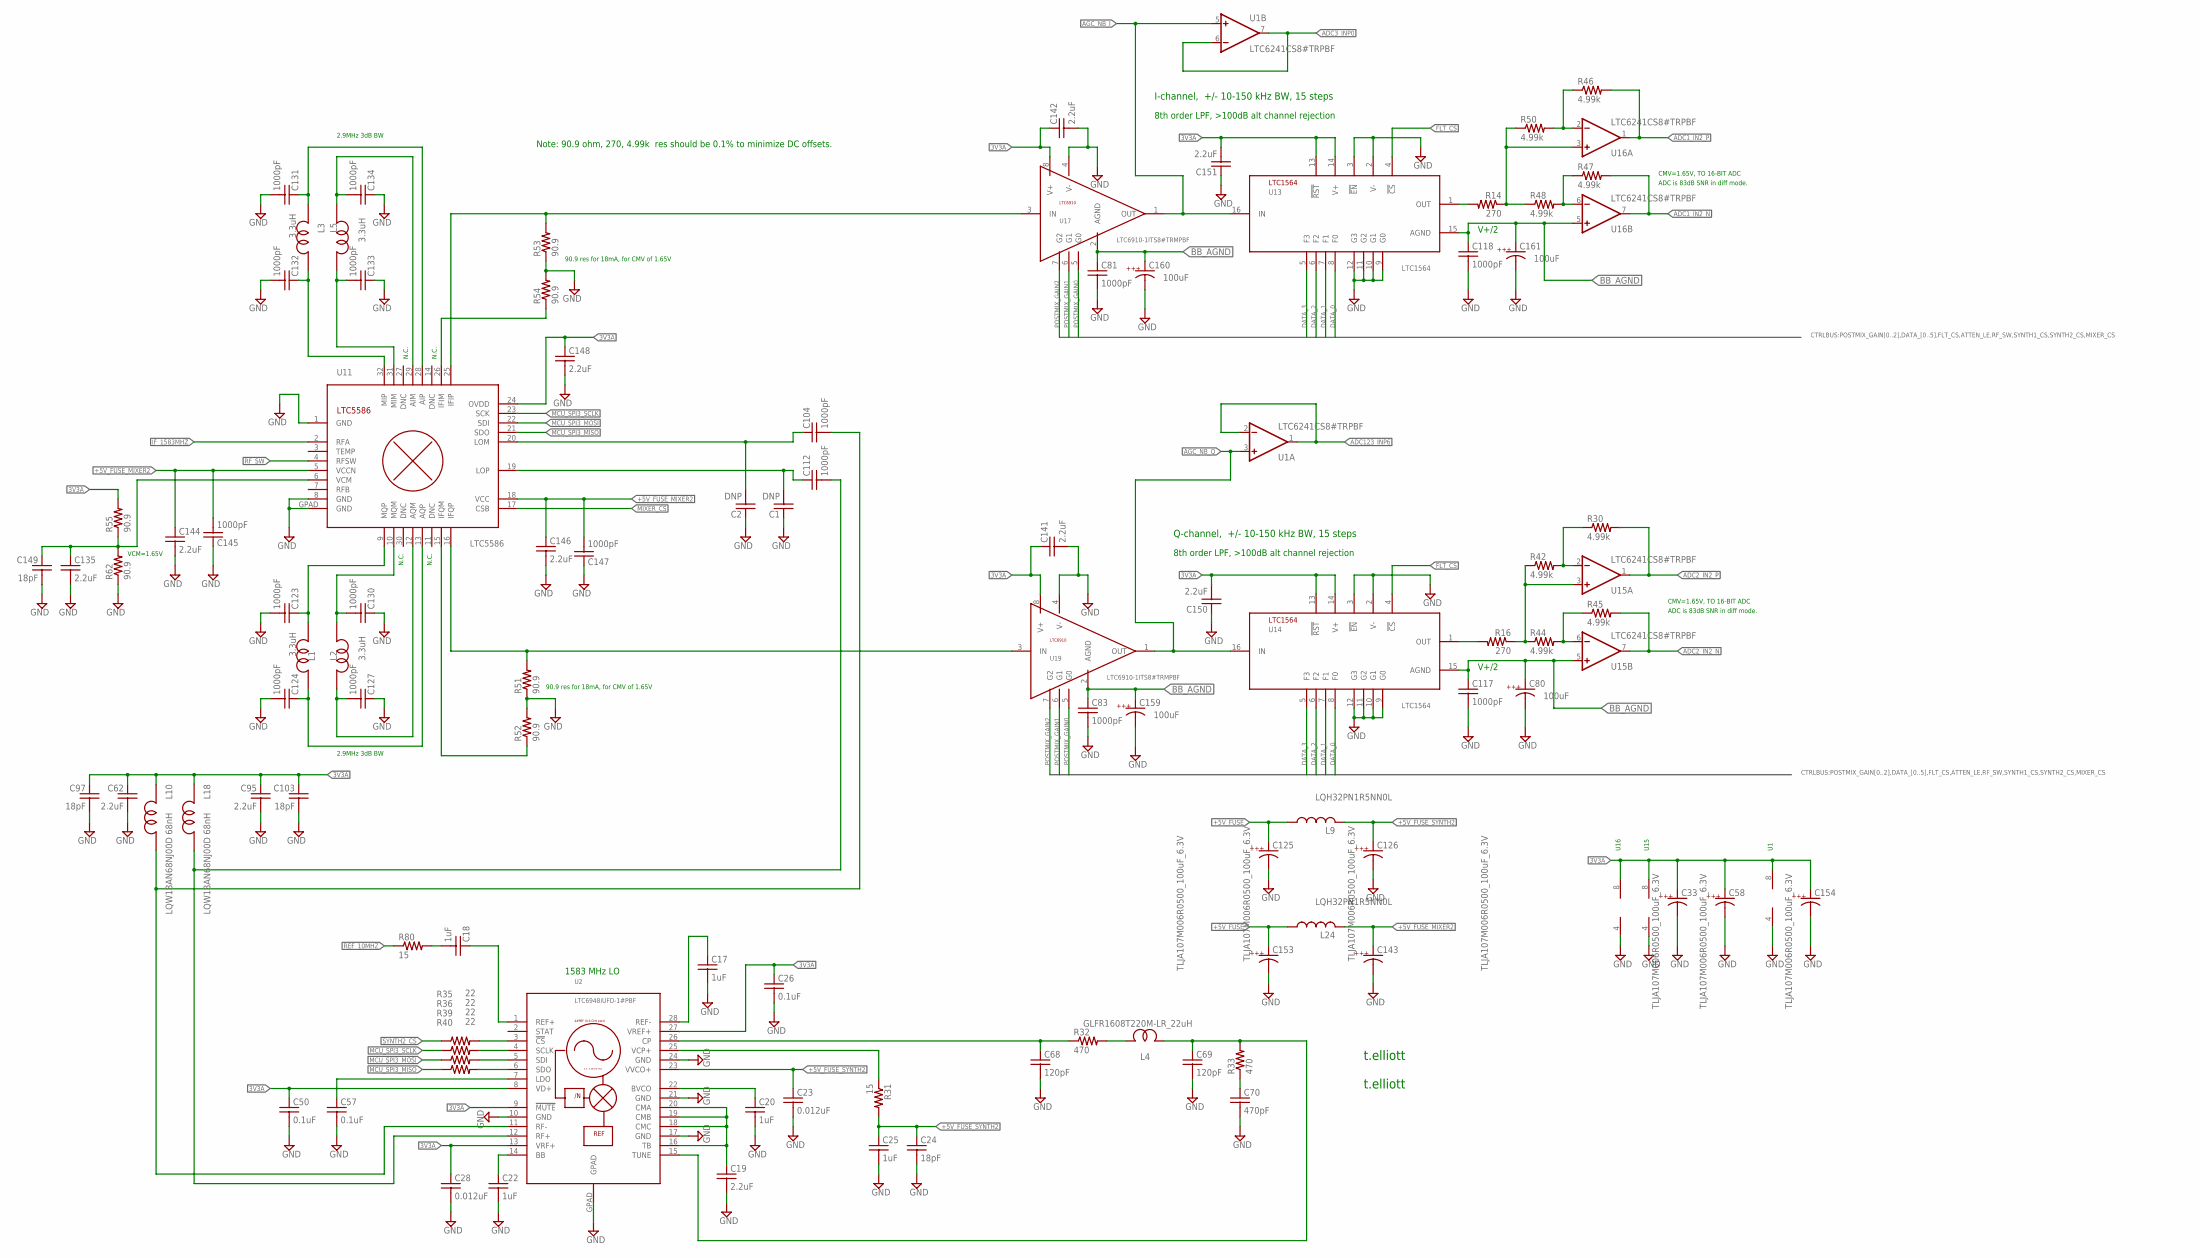
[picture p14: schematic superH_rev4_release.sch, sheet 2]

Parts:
C1, C2: DNP; C0402
C17, C20, C22, C25: 1uF; C0402
C18: 1uF; C0603
C19, C62, C95, C135: 2.2uF; C0603
C23, C28: 0.012uF; C0402
C24: 18pF; C0402
C26, C50, C57: 0.1uF; C0402
C33, C58, C125, C126, C143, C153, C154: TLJA107M006R0500_100uF_6.3V; 1210K
C68, C69: 120pF; C0402
C70: 470pF; C0402
C80, C159, C160, C161: 100uF; 1210K
C81, C83, C117, C118, C123, C124, C127, C130, C131, C132, C133, C134: 1000pF; C0603
C97, C103, C149: 18pF; C0603
C104, C112, C145, C147: 1000pF; C0402
C141, C142, C144, C146, C148, C150, C151: 2.2uF; C0402
L1, L2, L3, L5: 3.3uH; MURATA_LQW_0603
L4: GLFR1608T220M-LR_22uH; 0603
L9, L24: LQH32PN1R5NN0L; L3225M; PARTNUMBER ELJ-PA331KF
L10, L18: LQW18AN68NJ00D 68nH; MURATA_LQW_0603
R14, R16: 270; R0603
R30, R42, R44, R45, R46, R47, R48, R50: 4.99k; R0402
R31, R80: 15; R0402
R32, R33: 470; R0402
R35, R36, R39, R40: 22; R0603_COMPACT
R51, R52, R53, R54, R55, R62: 90.9; R0402
U1, U15, U16: LTC6241CS8#TRPBF; SO08
U2: LTC6948IUFD-1#PBF; QFN28_NONSQ
U11: LTC5586; QFN32
U13, U14: LTC1564; SSOP16
U17, U19: LTC6910-1ITS8#TRMPBF; TSOT-23-8

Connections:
3V3A: C26.1, C28.1, C33.A, C50.1, C58.A, C62.1, C95.1, C97.1, C103.1, C141.1, C142.1, C148.1, C150.2, C151.2, C154.A, L10.2, L18.2, R55.2, U1.8 (V+), U2.8 (VD+), U2.9 (!MUTE), U2.13 (VRF+), U2.27 (VREF+), U11.24 (OVDD), U13.13 (!RST), U13.14 (V+), U14.13 (!RST), U14.14 (V+), U15.8 (V+), U16.8 (V+), U17.8 (V+), U19.8 (V+); also elsewhere on the board
+5V_FUSE: C125.A, C153.A, L9.1, L24.1; also elsewhere on the board
+5V_FUSE_MIXER2: C143.A, C144.1, C145.2, C146.1, C147.2, L24.2, U11.5 (VCCN), U11.18 (VCC)
+5V_FUSE_SYNTH2: C23.1, C24.1, C25.1, C126.A, L9.2, R31.2, U2.23 (VVCO+)
ADC1_IN2_N: R47.2, U16.7 (OUT); also elsewhere on the board
ADC1_IN2_P: R46.2, U16.1 (OUT); also elsewhere on the board
ADC2_IN2_N: R45.2, U15.7 (OUT); also elsewhere on the board
ADC2_IN2_P: R30.2, U15.1 (OUT); also elsewhere on the board
ADC3_INP0: U1.6 (-IN), U1.7 (OUT); also elsewhere on the board
ADC123_INP6: U1.1 (OUT), U1.2 (-IN); also elsewhere on the board
AGC_NB_I: U1.5 (+IN), U13.16 (IN), U17.1 (OUT)
AGC_NB_Q: U1.3 (+IN), U14.16 (IN), U19.1 (OUT)
BB_AGND: C80.A, C81.1, C83.1, C117.1, C118.1, C159.A, C160.A, C161.A, U13.15 (AGND), U14.15 (AGND), U15.5 (+IN), U16.5 (+IN), U17.2 (AGND), U19.2 (AGND)
DATA_0: U13.8 (F0), U14.8 (F0); also elsewhere on the board
DATA_1: U13.7 (F1), U14.7 (F1); also elsewhere on the board
DATA_2: U13.6 (F2), U14.6 (F2); also elsewhere on the board
DATA_3: U13.5 (F3), U14.5 (F3); also elsewhere on the board
FLT_CS: U13.4 (!CS), U14.4 (!CS); also elsewhere on the board
GND: C1.1, C2.1, C17.2, C19.2, C20.2, C22.2, C23.2, C24.2, C25.2, C26.2, C28.2, C33.C, C50.2, C57.2, C58.C, C62.2, C68.2, C69.2, C70.2, C80.C, C81.2, C83.2, C95.2, C97.2, C103.2, C117.2, C118.2, C123.2, C124.2, C125.C, C126.C, C127.1, C130.1, C131.2, C132.2, C133.1, C134.1, C135.2, C141.2, C142.2, C143.C, C144.2, C145.1, C146.2, C147.1, C148.2, C149.2, C150.1, C151.1, C153.C, C154.C, C159.C, C160.C, C161.C, R51.1, R52.2, R53.1, R54.2, R62.1, U1.4 (V-), U2.10 (GND), U2.17 (GND), U2.21 (GND), U2.24 (GND), U2.GPAD, U11.1 (GND), U11.8 (GND), U11.GPAD (GND), U13.2 (V-), U13.3 (!EN), U13.9 (G0), U13.10 (G1), U13.11 (G2), U13.12 (G3), U14.2 (V-), U14.3 (!EN), U14.9 (G0), U14.10 (G1), U14.11 (G2), U14.12 (G3), U15.4 (V-), U16.4 (V-), U17.4 (V-), U19.4 (V-); also elsewhere on the board
IFI_N: R54.1, U11.26 (IFIM)
IFI_P: R53.2, U11.25 (IFIP), U17.3 (IN)
IFQ_N: R52.1, U11.15 (IFQM)
IFQ_P: R51.2, U11.16 (IFQP), U19.3 (IN)
IF_1583MHZ: U11.2 (RFA); also elsewhere on the board
LO_N: C2.2, C104.1, U11.20 (LOM)
LO_P: C1.2, C112.1, U11.19 (LOP)
MCU_SPI3_MISO: R40.1, U11.21 (SDO); also elsewhere on the board
MCU_SPI3_MOSI: R39.1, U11.22 (SDI); also elsewhere on the board
MCU_SPI3_SCLK: R36.1, U11.23 (SCK); also elsewhere on the board
MIXER_CS: U11.17 (CSB); also elsewhere on the board
unnamed: C18.1, U2.1 (REF+)
unnamed: C17.1, U2.28 (REF-)
unnamed: C19.1, U2.16 (TB), U2.18 (CMC), U2.19 (CMB), U2.20 (CMA)
unnamed: C20.1, U2.22 (BVCO)
unnamed: C22.1, U2.14 (BB)
unnamed: R31.1, U2.25 (VCP+)
unnamed: C57.1, U2.7 (LDO)
unnamed: C68.1, R32.1, U2.26 (CP)
unnamed: C70.1, R33.1
unnamed: C69.1, L4.2, R33.2, U2.15 (TUNE)
unnamed: L4.1, R32.2
unnamed: R35.2, U2.3 (!CS)
unnamed: R36.2, U2.4 (SCLK)
unnamed: R39.2, U2.5 (SDI)
unnamed: R40.2, U2.6 (SDO)
unnamed: R47.1, R48.2, U16.6 (-IN)
unnamed: R30.1, R42.2, U15.2 (-IN)
unnamed: R44.2, R45.1, U15.6 (-IN)
unnamed: R16.1, R42.1, R44.1, U15.3 (+IN)
unnamed: R16.2, U14.1 (OUT)
unnamed: R14.2, U13.1 (OUT)
unnamed: R46.1, R50.2, U16.2 (-IN)
unnamed: R14.1, R48.1, R50.1, U16.3 (+IN)
unnamed: C130.2, L2.1, U11.10 (MQM)
unnamed: C123.1, L1.2, U11.9 (MQP)
unnamed: C127.2, L2.2, U11.12 (AQM)
unnamed: C124.1, L1.1, U11.13 (AQP)
unnamed: C133.2, L5.2, U11.31 (MIM)
unnamed: C132.1, L3.1, U11.32 (MIP)
unnamed: C131.1, L3.2, U11.28 (AIP)
unnamed: C134.2, L5.1, U11.29 (AIM)
unnamed: C135.1, C149.1, R55.1, R62.2, U11.6 (VCM)
unnamed: C18.2, R80.2
POSTMIX_GAIN0: U17.5 (G0), U19.5 (G0); also elsewhere on the board
POSTMIX_GAIN1: U17.6 (G1), U19.6 (G1); also elsewhere on the board
POSTMIX_GAIN2: U17.7 (G2), U19.7 (G2); also elsewhere on the board
REF_10MHZ: R80.1; also elsewhere on the board
RF_SW: U11.4 (RFSW); also elsewhere on the board
SYNTH2_CS: R35.1; also elsewhere on the board
SYNTH2_N: C104.2, L10.1, U2.11 (RF-)
SYNTH2_P: C112.2, L18.1, U2.12 (RF+)

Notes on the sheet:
t.elliott
1583 MHz LO
V+/2
CMV=1.65V, TO 16-BIT ADC
8th order LPF, >100dB alt channel rejection
ADC is 83dB SNR in diff mode.
N.C.
90.9 res for 18mA, for CMV of 1.65V
VCM=1.65V
2.9MHz 3dB BW
Q-channel, +/- 10-150 kHz BW, 15 steps
I-channel, +/- 10-150 kHz BW, 15 steps
U16
U15
Note: 90.9 ohm, 270, 4.99k res should be 0.1% to minimize DC offsets.

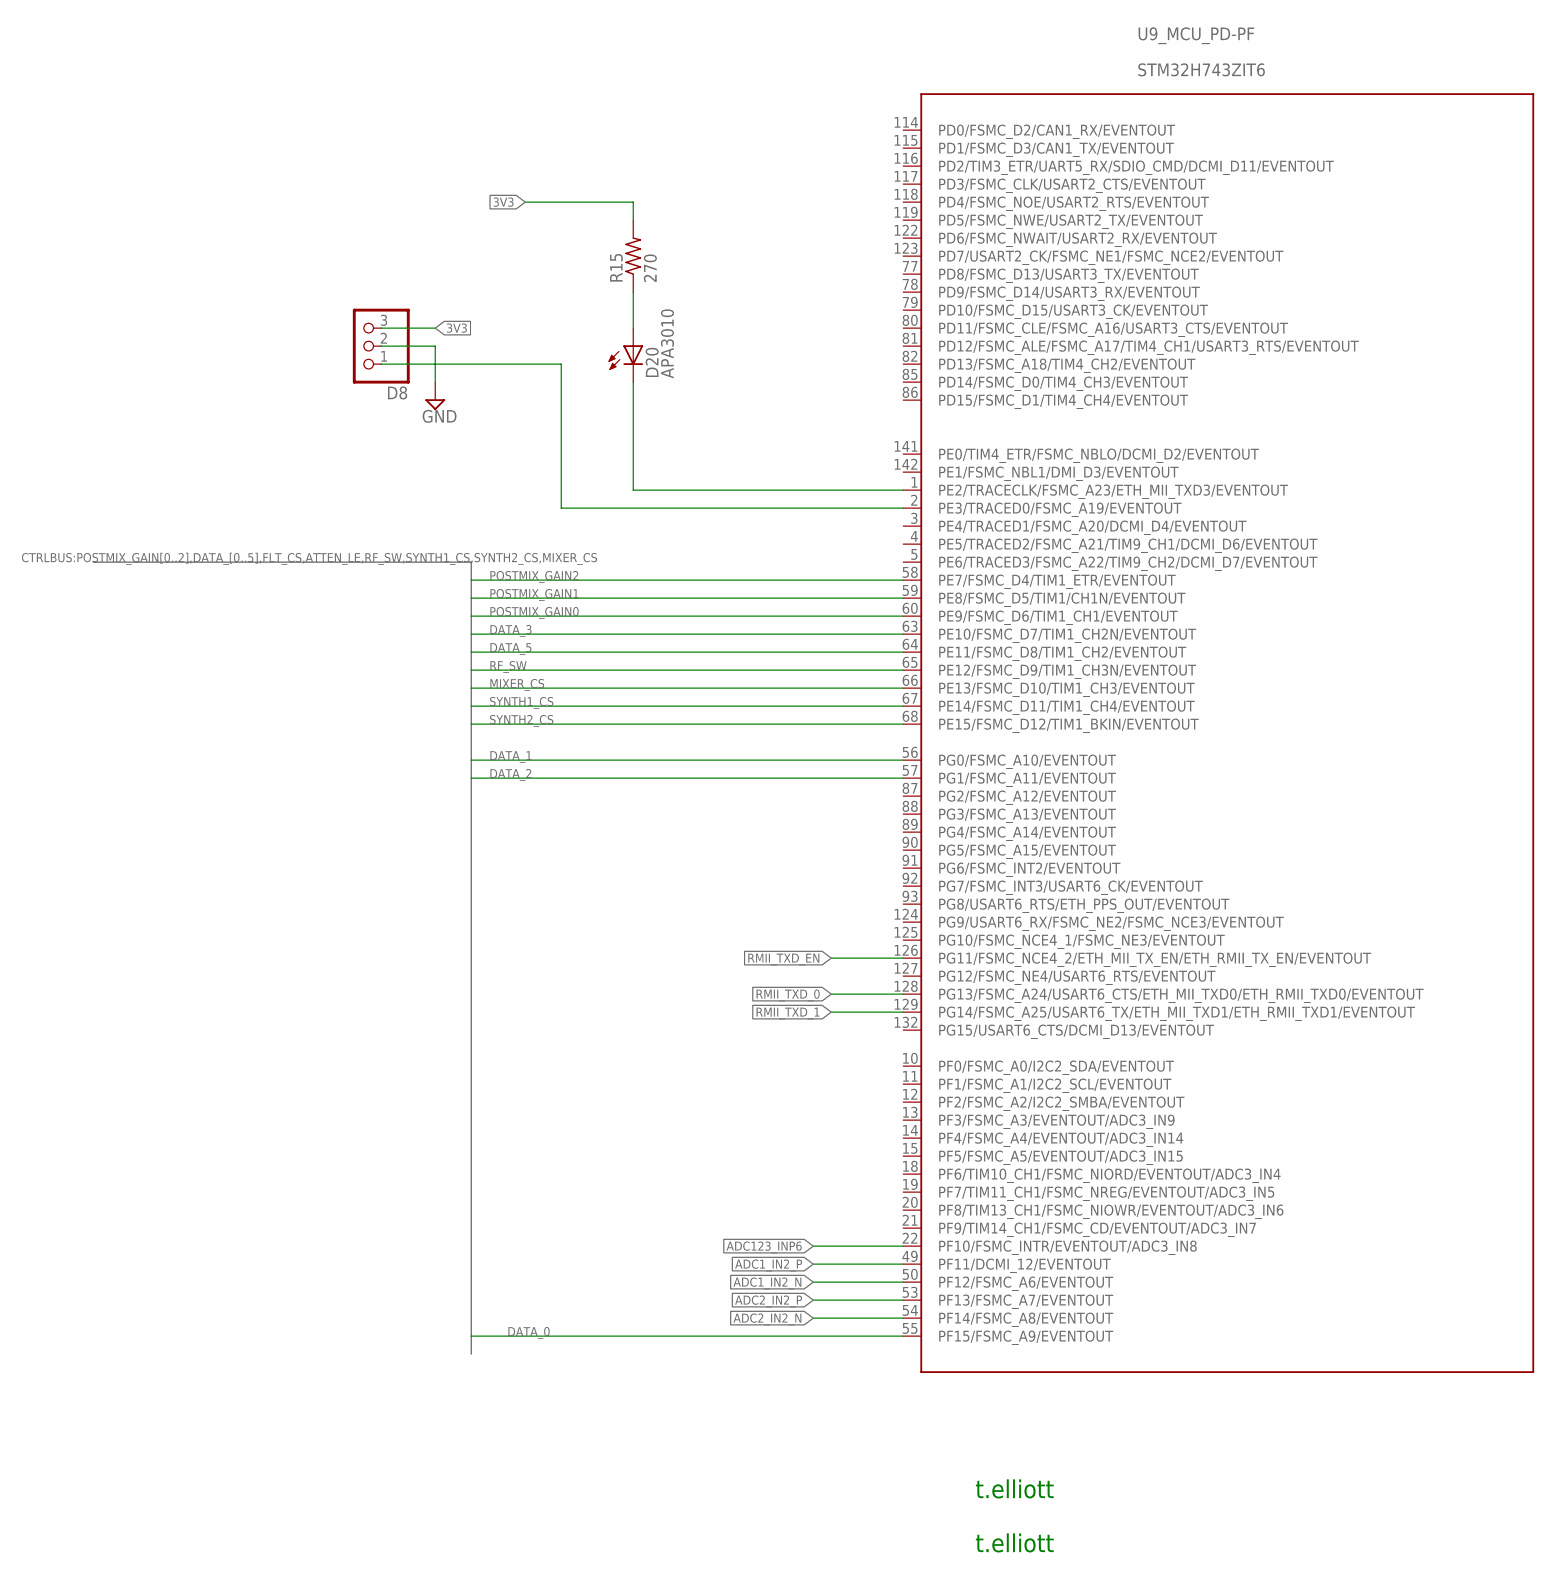
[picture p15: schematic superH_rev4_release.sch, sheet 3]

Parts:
D8: PINHD-1X3; 1X03
D20: APA3010; LED-APA3010_1PRIMARY
R15: 270; R0603
U9: STM32H743ZIT6; STM32F407_144

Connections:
3V3: D8.3, R15.2; also elsewhere on the board
ADC1_IN2_N: U9.50 (PF12/FSMC_A6/EVENTOUT); also elsewhere on the board
ADC1_IN2_P: U9.49 (PF11/DCMI_12/EVENTOUT); also elsewhere on the board
ADC2_IN2_N: U9.54 (PF14/FSMC_A8/EVENTOUT); also elsewhere on the board
ADC2_IN2_P: U9.53 (PF13/FSMC_A7/EVENTOUT); also elsewhere on the board
ADC123_INP6: U9.22 (PF10/FSMC_INTR/EVENTOUT/ADC3_IN8); also elsewhere on the board
DATA_0: U9.55 (PF15/FSMC_A9/EVENTOUT); also elsewhere on the board
DATA_1: U9.56 (PG0/FSMC_A10/EVENTOUT); also elsewhere on the board
DATA_2: U9.57 (PG1/FSMC_A11/EVENTOUT); also elsewhere on the board
DATA_3: U9.63 (PE10/FSMC_D7/TIM1_CH2N/EVENTOUT); also elsewhere on the board
DATA_5: U9.64 (PE11/FSMC_D8/TIM1_CH2/EVENTOUT); also elsewhere on the board
GND: D8.2; also elsewhere on the board
MIXER_CS: U9.66 (PE13/FSMC_D10/TIM1_CH3/EVENTOUT); also elsewhere on the board
unnamed: D20.1 (C), U9.1 (PE2/TRACECLK/FSMC_A23/ETH_MII_TXD3/EVEN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)
unnamed: D8.1, U9.2 (PE3/TRACED0/FSMC_A19/EVENTOUT)
unnamed: D20.2 (A), R15.1
POSTMIX_GAIN0: U9.60 (PE9/FSMC_D6/TIM1_CH1/EVENTOUT); also elsewhere on the board
POSTMIX_GAIN1: U9.59 (PE8/FSMC_D5/TIM1/CH1N/EVENTOUT); also elsewhere on the board
POSTMIX_GAIN2: U9.58 (PE7/FSMC_D4/TIM1_ETR/EVENTOUT); also elsewhere on the board
RF_SW: U9.65 (PE12/FSMC_D9/TIM1_CH3N/EVENTOUT); also elsewhere on the board
RMII_TXD_0: U9.128 (PG13/FSMC_A24/USART6_CTS/ETH_MII_TXD0/E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); also elsewhere on the board
RMII_TXD_1: U9.129 (PG14/FSMC_A25/USART6_TX/ETH_MII_TXD1/ET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); also elsewhere on the board
RMII_TXD_EN: U9.126 (PG11/FSMC_NCE4_2/ETH_MII_TX_EN/ETH_RMII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); also elsewhere on the board
SYNTH1_CS: U9.67 (PE14/FSMC_D11/TIM1_CH4/EVENTOUT); also elsewhere on the board
SYNTH2_CS: U9.68 (PE15/FSMC_D12/TIM1_BKIN/EVENTOUT); also elsewhere on the board

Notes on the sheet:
t.elliott

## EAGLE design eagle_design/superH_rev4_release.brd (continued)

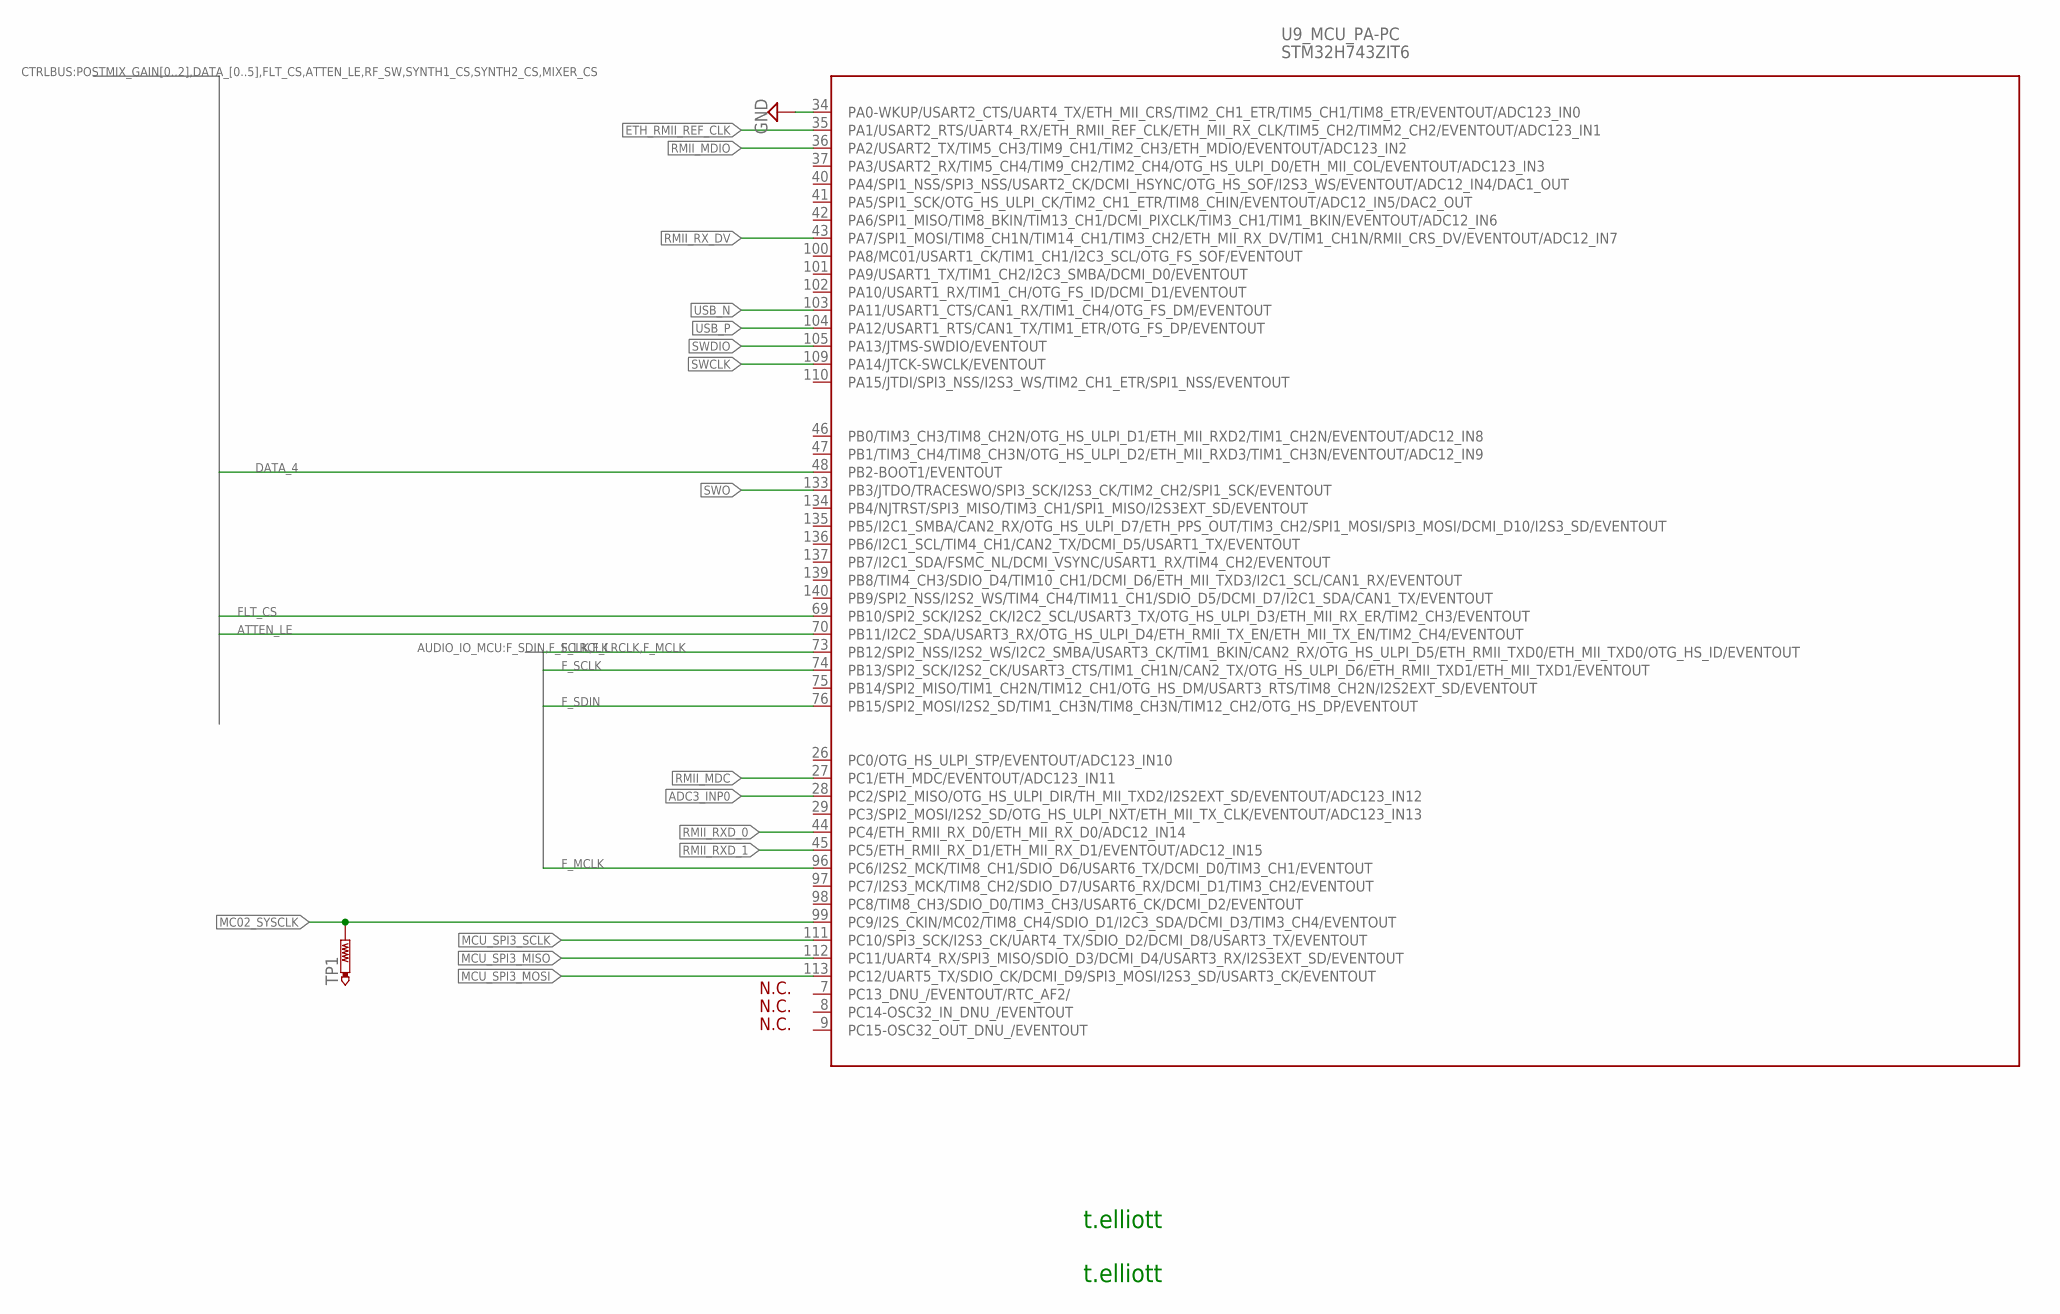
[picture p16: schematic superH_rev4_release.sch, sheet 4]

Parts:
TP1: PTR1TP08R; TP08R
U9: STM32H743ZIT6; STM32F407_144

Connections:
ADC3_INP0: U9.28 (PC2/SPI2_MISO/OTG_HS_ULPI_DIR/TH_MII_TX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); also elsewhere on the board
ATTEN_LE: U9.70 (PB11/I2C2_SDA/USART3_RX/OTG_HS_ULPI_D4/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); also elsewhere on the board
DATA_4: U9.48 (PB2-BOOT1/EVENTOUT); also elsewhere on the board
ETH_RMII_REF_CLK: U9.35 (PA1/USART2_RTS/UART4_RX/ETH_RMII_REF_CL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); also elsewhere on the board
FLT_CS: U9.69 (PB10/SPI2_SCK/I2S2_CK/I2C2_SCL/USART3_T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); also elsewhere on the board
F_LRCLK: U9.73 (PB12/SPI2_NSS/I2S2_WS/I2C2_SMBA/USART3_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); also elsewhere on the board
F_MCLK: U9.96 (PC6/I2S2_MCK/TIM8_CH1/SDIO_D6/USART6_TX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); also elsewhere on the board
F_SCLK: U9.74 (PB13/SPI2_SCK/I2S2_CK/USART3_CTS/TIM1_C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); also elsewhere on the board
F_SDIN: U9.76 (PB15/SPI2_MOSI/I2S2_SD/TIM1_CH3N/TIM8_C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); also elsewhere on the board
GND: U9.34 (PA0-WKUP/USART2_CTS/UART4_TX/ETH_MII_CR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); also elsewhere on the board
MC02_SYSCLK: TP1.TP, U9.99 (PC9/I2S_CKIN/MC02/TIM8_CH4/SDIO_D1/I2C3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)
MCU_SPI3_MISO: U9.112 (PC11/UART4_RX/SPI3_MISO/SDIO_D3/DCMI_D4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); also elsewhere on the board
MCU_SPI3_MOSI: U9.113 (PC12/UART5_TX/SDIO_CK/DCMI_D9/SPI3_MOSI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); also elsewhere on the board
MCU_SPI3_SCLK: U9.111 (PC10/SPI3_SCK/I2S3_CK/UART4_TX/SDIO_D2/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); also elsewhere on the board
RMII_MDC: U9.27 (PC1/ETH_MDC/EVENTOUT/ADC123_IN11); also elsewhere on the board
RMII_MDIO: U9.36 (PA2/USART2_TX/TIM5_CH3/TIM9_CH1/TIM2_CH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); also elsewhere on the board
RMII_RXD_0: U9.44 (PC4/ETH_RMII_RX_D0/ETH_MII_RX_D0/ADC12_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); also elsewhere on the board
RMII_RXD_1: U9.45 (PC5/ETH_RMII_RX_D1/ETH_MII_RX_D1/EVENTO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); also elsewhere on the board
RMII_RX_DV: U9.43 (PA7/SPI1_MOSI/TIM8_CH1N/TIM14_CH1/TIM3_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); also elsewhere on the board
SWCLK: U9.109 (PA14/JTCK-SWCLK/EVENTOUT); also elsewhere on the board
SWDIO: U9.105 (PA13/JTMS-SWDIO/EVENTOUT); also elsewhere on the board
SWO: U9.133 (PB3/JTDO/TRACESWO/SPI3_SCK/I2S3_CK/TIM2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); also elsewhere on the board
USB_N: U9.103 (PA11/USART1_CTS/CAN1_RX/TIM1_CH4/OTG_FS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); also elsewhere on the board
USB_P: U9.104 (PA12/USART1_RTS/CAN1_TX/TIM1_ETR/OTG_FS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); also elsewhere on the board

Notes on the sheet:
t.elliott

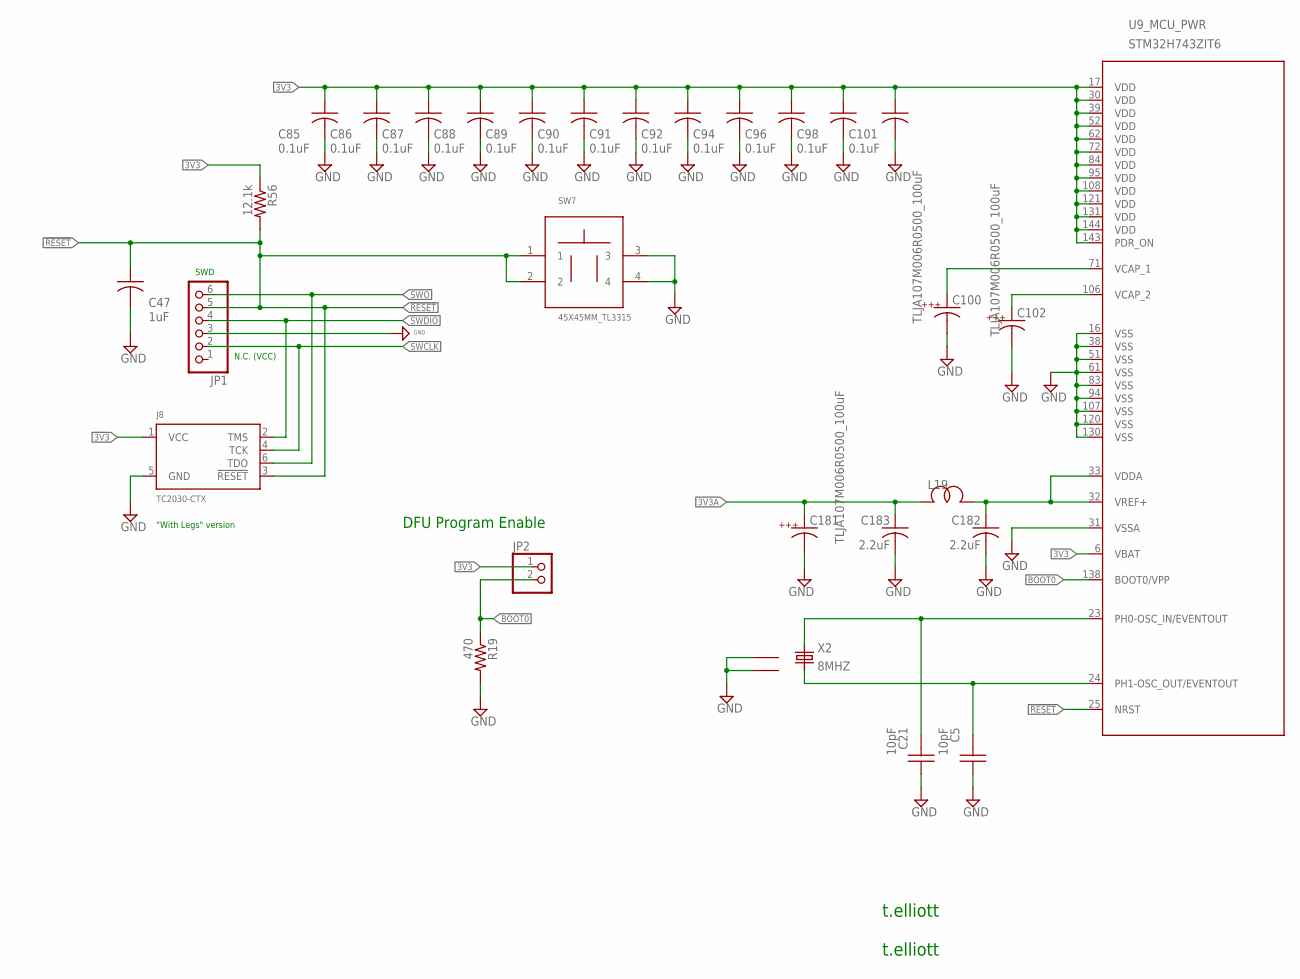
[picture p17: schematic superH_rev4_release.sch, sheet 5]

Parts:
C5, C21: 10pF; C0402
C47: 1uF; 0402
C85, C86, C87, C88, C89, C90, C91, C92, C94, C96, C98, C101: 0.1uF; 0402
C100, C102, C181: TLJA107M006R0500_100uF; 1210K
C182, C183: 2.2uF; C0805
J8: TC2030-CTX; TC2030-IDC
JP1: PINHD-1X6; 1X06
JP2: PINHD-1X2; 1X02
L19: WE-CBF_0603; 0603
R19: 470; R0402
R56: 12.1k; R0603
SW7: 45X45MM_TL3315; PBUT_SW_TACTILE_4_5MMX4_5MM
U9: STM32H743ZIT6; STM32F407_144
X2: 8MHZ; ECS-250-20-30B-DU_CRYSTAL

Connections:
3V3: C85.1 (A), C86.1 (A), C87.1 (A), C88.1 (A), C89.1 (A), C90.1 (A), C91.1 (A), C92.1 (A), C94.1 (A), C96.1 (A), C98.1 (A), C101.1 (A), J8.1 (VCC), JP2.1, R56.1, U9.6 (VBAT), U9.17 (VDD), U9.30 (VDD), U9.39 (VDD), U9.52 (VDD), U9.62 (VDD), U9.72 (VDD), U9.84 (VDD), U9.95 (VDD), U9.108 (VDD), U9.121 (VDD), U9.131 (VDD), U9.143 (PDR_ON), U9.144 (VDD); also elsewhere on the board
3V3A: C181.A, C183.1, L19.1; also elsewhere on the board
20MHZ_REF: C21.2, U9.23 (PH0-OSC_IN/EVENTOUT), X2.1
!RESET: C47.1 (A), J8.3 (!RESET), JP1.5, R56.2, SW7.1, SW7.2, U9.25 (NRST); also elsewhere on the board
BOOT0: JP2.2, R19.1, U9.138 (BOOT0/VPP)
GND: C5.1, C21.1, C47.2 (C), C85.2 (C), C86.2 (C), C87.2 (C), C88.2 (C), C89.2 (C), C90.2 (C), C91.2 (C), C92.2 (C), C94.2 (C), C96.2 (C), C98.2 (C), C100.C, C101.2 (C), C102.C, C181.C, C182.2, C183.2, J8.5 (GND), JP1.3, R19.2, SW7.3, SW7.4, U9.16 (VSS), U9.31 (VSSA), U9.38 (VSS), U9.51 (VSS), U9.61 (VSS), U9.83 (VSS), U9.94 (VSS), U9.107 (VSS), U9.120 (VSS), U9.130 (VSS), X2.GND@1 (1), X2.GND@2 (2); also elsewhere on the board
unnamed: C182.1, L19.2, U9.32 (VREF+), U9.33 (VDDA)
unnamed: C102.A, U9.106 (VCAP_2)
unnamed: C100.A, U9.71 (VCAP_1)
SWCLK: J8.4 (TCK), JP1.2; also elsewhere on the board
SWDIO: J8.2 (TMS), JP1.4; also elsewhere on the board
SWO: J8.6 (TDO), JP1.6; also elsewhere on the board
X2: C5.2, U9.24 (PH1-OSC_OUT/EVENTOUT), X2.3

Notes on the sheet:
t.elliott
SWD
N.C. (VCC)
"With Legs" version
DFU Program Enable

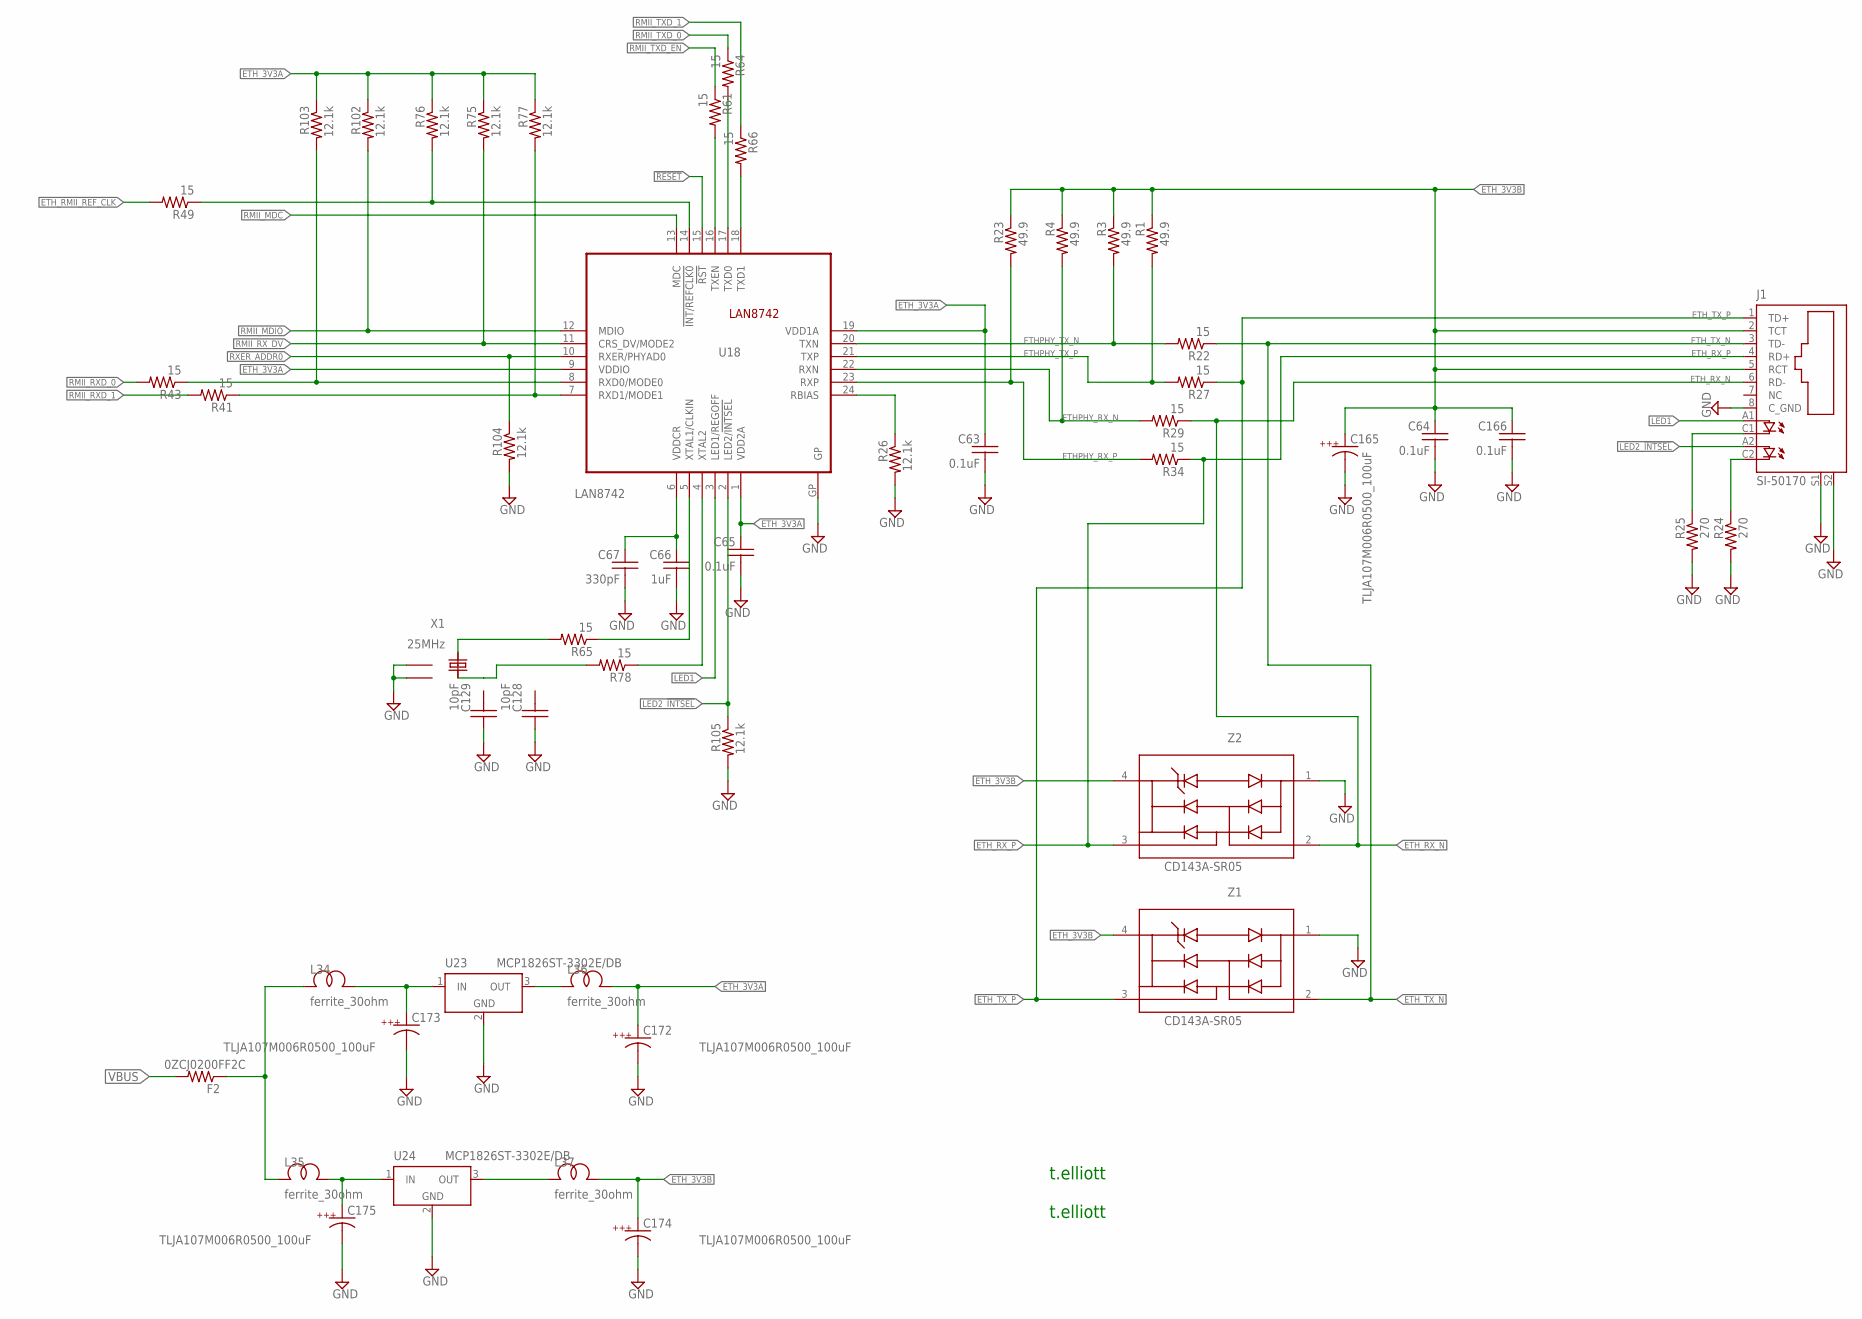
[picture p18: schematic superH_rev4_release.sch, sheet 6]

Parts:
C63, C64, C65, C166: 0.1uF; C0603
C66: 1uF; C0603
C67: 330pF; C0603
C128, C129: 10pF; C0402
C165, C172, C173, C174, C175: TLJA107M006R0500_100uF; 1210K
F2: 0ZCJ0200FF2C; R1206
J1: SI-50170
L34, L35, L36, L37: ferrite_30ohm; 0603
R1, R3, R4, R23: 49.9; R0603
R22, R27, R29, R34, R41, R43, R49, R61, R64, R65, R66, R78: 15; R0402
R24, R25: 270; R0603
R26, R75, R76, R77, R102, R103, R104, R105: 12.1k; R0603
U18: LAN8742; QFN-24
U23, U24: MCP1826ST-3302E/DB; SOT223
X1: 25MHz; ECS-250-20-30B-DU_CRYSTAL
Z1, Z2: CD143A-SR05; SR2.8.TCT_1PRIMARY

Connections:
!RESET: U18.15 (!RST); also elsewhere on the board
ETHPHY_RX_N: R4.2, R29.2, U18.22 (RXN)
ETHPHY_RX_P: R23.2, R34.2, U18.23 (RXP)
ETHPHY_TX_N: R3.2, R22.2, U18.20 (TXN)
ETHPHY_TX_P: R1.2, R27.2, U18.21 (TXP)
ETH_3V3A: C63.1, C65.1, C172.A, L36.2, R75.1, R76.1, R77.1, R102.1, R103.1, U18.1 (VDD2A), U18.9 (VDDIO), U18.19 (VDD1A)
ETH_3V3B: C64.1, C165.A, C166.1, C174.A, J1.2 (TCT), J1.5 (RCT), L37.2, R1.1, R3.1, R4.1, R23.1, Z1.4 (REF), Z2.4 (REF)
ETH_RMII_REF_CLK: R49.2; also elsewhere on the board
ETH_RX_N: J1.6 (RD-), R29.1, Z2.2 (I/O)
ETH_RX_P: J1.4 (RD+), R34.1, Z2.3 (I/O)
ETH_TX_N: J1.3 (TD-), R22.1, Z1.2 (I/O)
ETH_TX_P: J1.1 (TD+), R27.1, Z1.3 (I/O)
ETH_VIN: F2.1, L34.1, L35.1
GND: C63.2, C64.2, C65.2, C66.2, C67.2, C128.1, C129.1, C165.C, C166.2, C172.C, C173.C, C174.C, C175.C, J1.8 (C_GND), J1.S1, J1.S2, R24.2, R25.2, R26.2, R104.2, R105.2, U18.GP, U23.2 (GND), U23.4 (GND), U24.2 (GND), U24.4 (GND), X1.GND@1 (1), X1.GND@2 (2), Z1.1 (GND), Z2.1 (GND); also elsewhere on the board
LED1: J1.A1 (A), U18.3 (LED1/REGOFF)
LED2_!INTSEL: J1.A2 (A1), R105.1, U18.2 (LED2/!INTSEL)
unnamed: C173.A, L34.2, U23.1 (IN)
unnamed: R26.1, U18.24 (RBIAS)
unnamed: C66.1, C67.1, U18.6 (VDDCR)
unnamed: J1.C2 (C1), R24.1
unnamed: J1.C1 (C), R25.1
unnamed: R78.1, U18.4 (XTAL2)
unnamed: R65.1, U18.5 (XTAL1/CLKIN)
unnamed: C175.A, L35.2, U24.1 (IN)
unnamed: L37.1, U24.3 (OUT)
unnamed: L36.1, U23.3 (OUT)
unnamed: R78.2, X1.3
unnamed: R65.2, X1.1
REF_CLK: R49.1, R76.2, U18.14 (!INT/REFCLK0)
RMII_MDC: U18.13 (MDC); also elsewhere on the board
RMII_MDIO: R102.2, U18.12 (MDIO); also elsewhere on the board
RMII_RXD_0: R43.2; also elsewhere on the board
RMII_RXD_1: R41.2; also elsewhere on the board
RMII_RX_DV: R75.2, U18.11 (CRS_DV/MODE2); also elsewhere on the board
RMII_TXD_0: R64.1; also elsewhere on the board
RMII_TXD_1: R66.1; also elsewhere on the board
RMII_TXD_EN: R61.1; also elsewhere on the board
RXD0: R43.1, R103.2, U18.8 (RXD0/MODE0)
RXD1: R41.1, R77.2, U18.7 (RXD1/MODE1)
RXER_ADDR0: R104.1, U18.10 (RXER/PHYAD0)
TXD0: R64.2, U18.17 (TXD0)
TXD1: R66.2, U18.18 (TXD1)
TXEN: R61.2, U18.16 (TXEN)
VBUS: F2.2; also elsewhere on the board

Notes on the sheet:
t.elliott

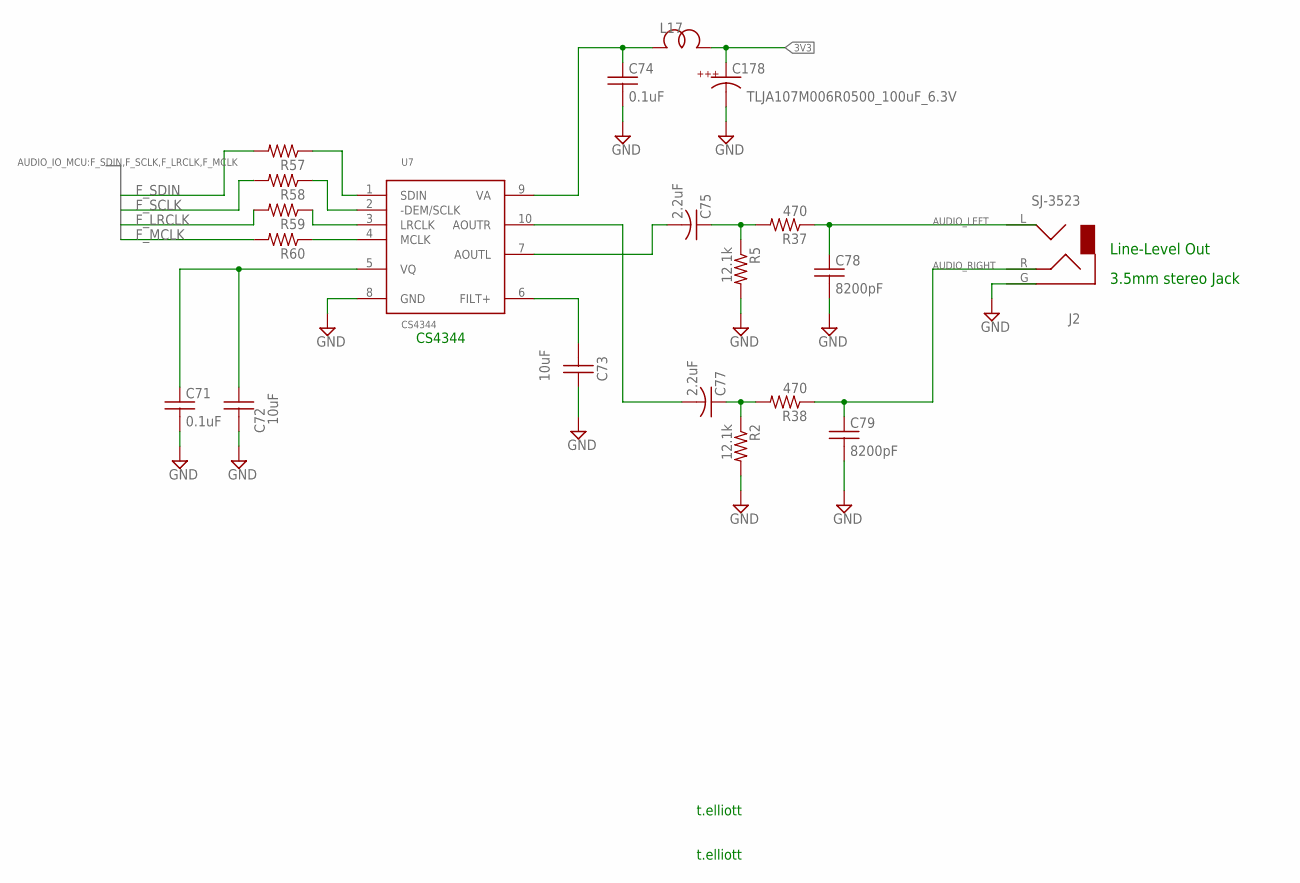
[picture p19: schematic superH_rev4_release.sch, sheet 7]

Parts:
C71, C74: 0.1uF; C0603
C72, C73: 10uF; C0805
C75, C77: 2.2uF; C0805
C78, C79: 8200pF; C0603
C178: TLJA107M006R0500_100uF_6.3V; 1210K
J2: SJ-3523
L17: WE-CBF_0603; 0603
R2, R5: 12.1k; R0603
R37, R38, R57, R58, R59, R60: 470; R0402
U7: CS4344; MSOP10

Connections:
3V3: C178.A, L17.2; also elsewhere on the board
AUDIO_LEFT: C79.1, J2.R, R38.1
AUDIO_RIGHT: C78.1, J2.L, R37.1
F_LRCLK: R59.2; also elsewhere on the board
F_MCLK: R60.2; also elsewhere on the board
F_SCLK: R58.2; also elsewhere on the board
F_SDIN: R57.2; also elsewhere on the board
GND: C71.2, C72.2, C73.1, C74.2, C78.2, C79.2, C178.C, J2.G, R2.2, R5.2, U7.8 (GND); also elsewhere on the board
unnamed: C77.2, U7.10 (AOUTR)
unnamed: R60.1, U7.4 (MCLK)
unnamed: R59.1, U7.3 (LRCLK)
unnamed: R58.1, U7.2 (-DEM/SCLK)
unnamed: R57.1, U7.1 (SDIN)
unnamed: C73.2, U7.6 (FILT+)
unnamed: C71.1, C72.1, U7.5 (VQ)
unnamed: C75.2, U7.7 (AOUTL)
unnamed: C75.1, R5.1, R37.2
unnamed: C77.1, R2.1, R38.2
unnamed: C74.1, L17.1, U7.9 (VA)

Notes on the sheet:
t.elliott
CS4344
Line-Level Out
3.5mm stereo Jack

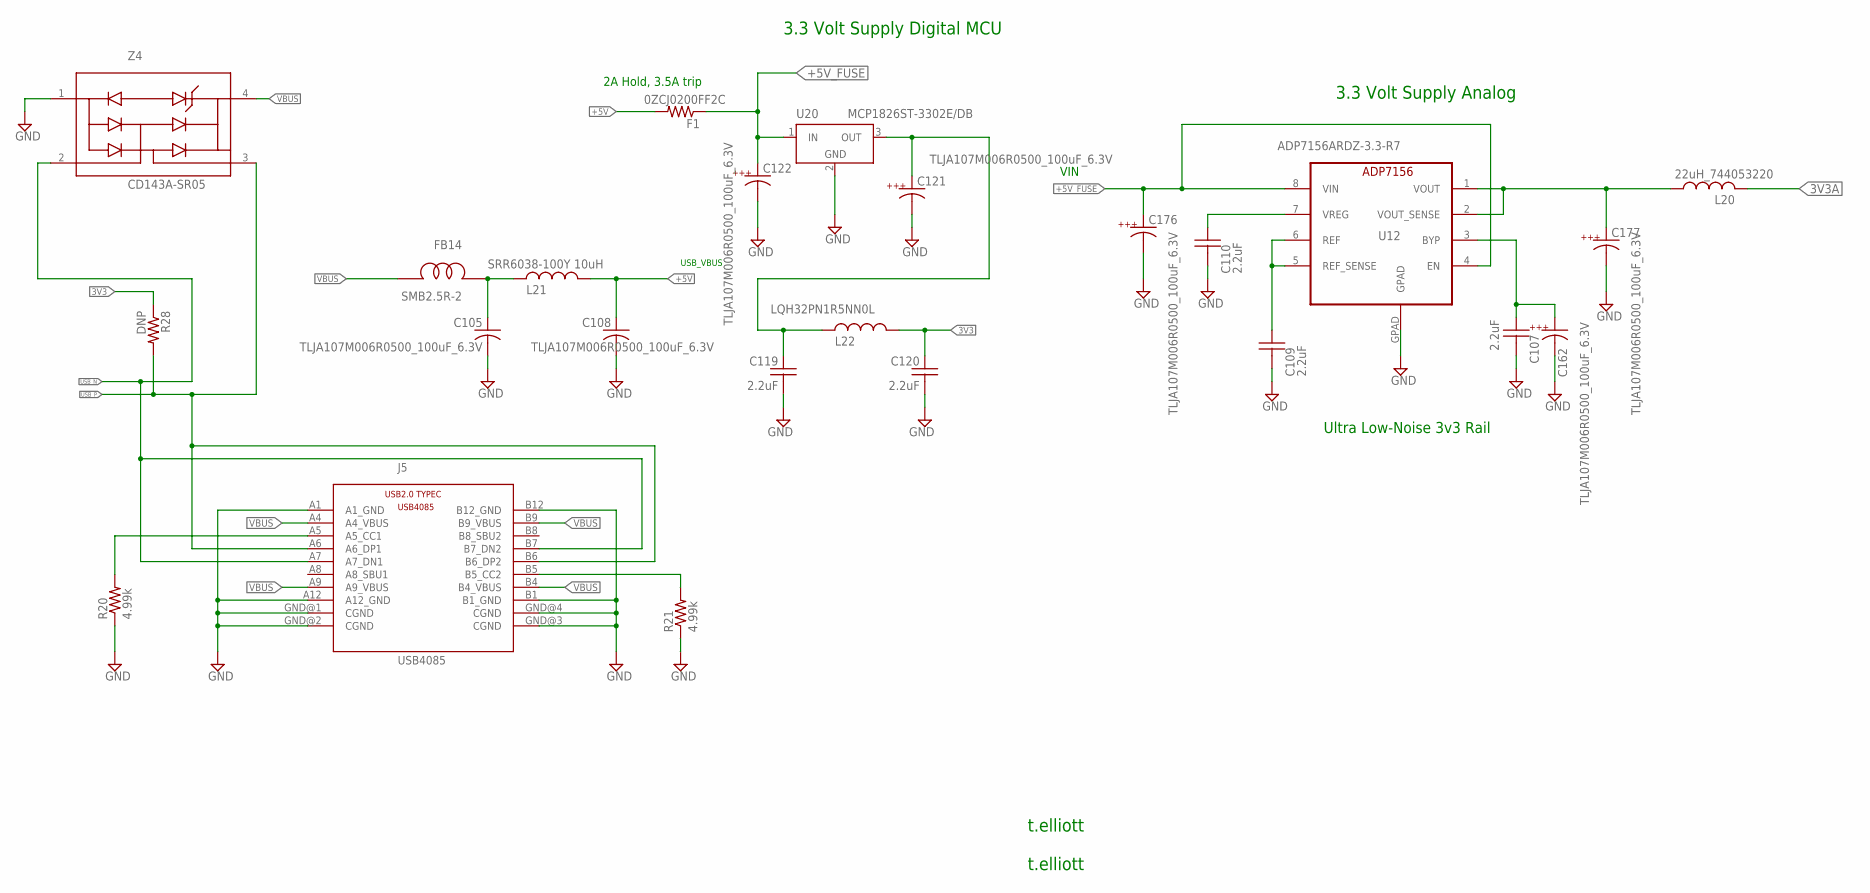
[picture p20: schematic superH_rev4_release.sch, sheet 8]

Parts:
C105, C108, C121, C122, C162, C176, C177: TLJA107M006R0500_100uF_6.3V; 1210K
C107, C109, C110: 2.2uF; C0805
C119, C120: 2.2uF; C0603
F1: 0ZCJ0200FF2C; R1206
FB14: SMB2.5R-2; SMB2.5-2
J5: USB4085; GCT_PN_USB4085
L20: 22uH_744053220; POWER-CHOKE_WE-TPC
L21: SRR6038-100Y 10uH; POWER-CHOKE_WE-TPC
L22: LQH32PN1R5NN0L; L3225M; PARTNUMBER ELJ-PA331KF
R20, R21: 4.99k; R0402
R28: DNP; R0603
U12: ADP7156ARDZ-3.3-R7; SO8
U20: MCP1826ST-3302E/DB; SOT223
Z4: CD143A-SR05; SR2.8.TCT_1PRIMARY

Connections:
3V3: C120.1, L22.1, R28.1; also elsewhere on the board
3V3A: L20.2; also elsewhere on the board
3V3_VIN: C119.1, C121.A, L22.2, U20.3 (OUT)
+5V: C108.A, F1.2, L21.1
+5V_FUSE: C122.A, C176.A, F1.1, U12.4 (EN), U12.8 (VIN), U20.1 (IN); also elsewhere on the board
GND: C105.C, C107.2, C108.C, C109.2, C110.2, C119.2, C120.2, C121.C, C122.C, C162.C, C176.C, C177.C, J5.A1 (A1_GND), J5.A12 (A12_GND), J5.B1 (B1_GND), J5.B12 (B12_GND), J5.GND@1 (CGND), J5.GND@2 (CGND), J5.GND@3 (CGND), J5.GND@4 (CGND), R20.1, R21.1, U12.GPAD, U20.2 (GND), U20.4 (GND), Z4.1 (GND); also elsewhere on the board
unnamed: J5.B5 (B5_CC2), R21.2
unnamed: C177.A, L20.1, U12.1 (VOUT), U12.2 (VOUT_SENSE)
unnamed: C109.1, U12.5 (REF_SENSE), U12.6 (REF)
unnamed: C110.1, U12.7 (VREG)
unnamed: C107.1, C162.A, U12.3 (BYP)
unnamed: C105.A, FB14.P$2, L21.2
unnamed: J5.A5 (A5_CC1), R20.2
USB_N: J5.A7 (A7_DN1), J5.B7 (B7_DN2), Z4.2 (I/O); also elsewhere on the board
USB_P: J5.A6 (A6_DP1), J5.B6 (B6_DP2), R28.2, Z4.3 (I/O); also elsewhere on the board
VBUS: FB14.P$1, J5.A4 (A4_VBUS), J5.A9 (A9_VBUS), J5.B4 (B4_VBUS), J5.B9 (B9_VBUS), Z4.4 (REF); also elsewhere on the board

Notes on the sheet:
t.elliott
VIN
3.3 Volt Supply Digital MCU
USB_VBUS
Ultra Low-Noise 3v3 Rail
2A Hold, 3.5A trip
3.3 Volt Supply Analog

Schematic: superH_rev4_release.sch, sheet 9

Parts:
FAB1, FAB2, FAB3, FAB4, FAB5, FAB6: 2118724; RF_SHIELD
FID1, FID2, FID3, FID4: FIDUCIALSMD; FIDUCIAL
H1, H2, H3, H4, H5, H6: MOUNT-PAD-ROUND2.8; 2,8-PAD

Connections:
GND: FAB1.P$1, FAB1.P$2, FAB1.P$3, FAB1.P$4, FAB1.P$5, FAB1.P$6, FAB1.P$7, FAB1.P$8, FAB1.P$9, FAB1.P$10, FAB1.P$11, FAB1.P$12, FAB1.P$13, FAB1.P$14, FAB1.P$15, FAB1.P$16, FAB1.P$17, FAB1.P$18, FAB1.P$19, FAB1.P$20, FAB1.P$21, FAB1.P$22, FAB1.P$23, FAB1.P$24, FAB2.P$1, FAB2.P$2, FAB2.P$3, FAB2.P$4, FAB2.P$5, FAB2.P$6, FAB2.P$7, FAB2.P$8, FAB2.P$9, FAB2.P$10, FAB2.P$11, FAB2.P$12, FAB2.P$13, FAB2.P$14, FAB2.P$15, FAB2.P$16, FAB2.P$17, FAB2.P$18, FAB2.P$19, FAB2.P$20, FAB2.P$21, FAB2.P$22, FAB2.P$23, FAB2.P$24, FAB3.P$1, FAB3.P$2, FAB3.P$3, FAB3.P$4, FAB3.P$5, FAB3.P$6, FAB3.P$7, FAB3.P$8, FAB3.P$9, FAB3.P$10, FAB3.P$11, FAB3.P$12, FAB3.P$13, FAB3.P$14, FAB3.P$15, FAB3.P$16, FAB3.P$17, FAB3.P$18, FAB3.P$19, FAB3.P$20, FAB3.P$21, FAB3.P$22, FAB3.P$23, FAB3.P$24, FAB4.P$1, FAB4.P$2, FAB4.P$3, FAB4.P$4, FAB4.P$5, FAB4.P$6, FAB4.P$7, FAB4.P$8, FAB4.P$9, FAB4.P$10, FAB4.P$11, FAB4.P$12, FAB4.P$13, FAB4.P$14, FAB4.P$15, FAB4.P$16, FAB4.P$17, FAB4.P$18, FAB4.P$19, FAB4.P$20, FAB4.P$21, FAB4.P$22, FAB4.P$23, FAB4.P$24, FAB5.P$1, FAB5.P$2, FAB5.P$3, FAB5.P$4, FAB5.P$5, FAB5.P$6, FAB5.P$7, FAB5.P$8, FAB5.P$9, FAB5.P$10, FAB5.P$11, FAB5.P$12, FAB5.P$13, FAB5.P$14, FAB5.P$15, FAB5.P$16, FAB5.P$17, FAB5.P$18, FAB5.P$19, FAB5.P$20, FAB5.P$21, FAB5.P$22, FAB5.P$23, FAB5.P$24, FAB6.P$1, FAB6.P$2, FAB6.P$3, FAB6.P$4, FAB6.P$5, FAB6.P$6, FAB6.P$7, FAB6.P$8, FAB6.P$9, FAB6.P$10, FAB6.P$11, FAB6.P$12, FAB6.P$13, FAB6.P$14, FAB6.P$15, FAB6.P$16, FAB6.P$17, FAB6.P$18, FAB6.P$19, FAB6.P$20, FAB6.P$21, FAB6.P$22, FAB6.P$23, FAB6.P$24; also elsewhere on the board

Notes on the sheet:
t.elliott

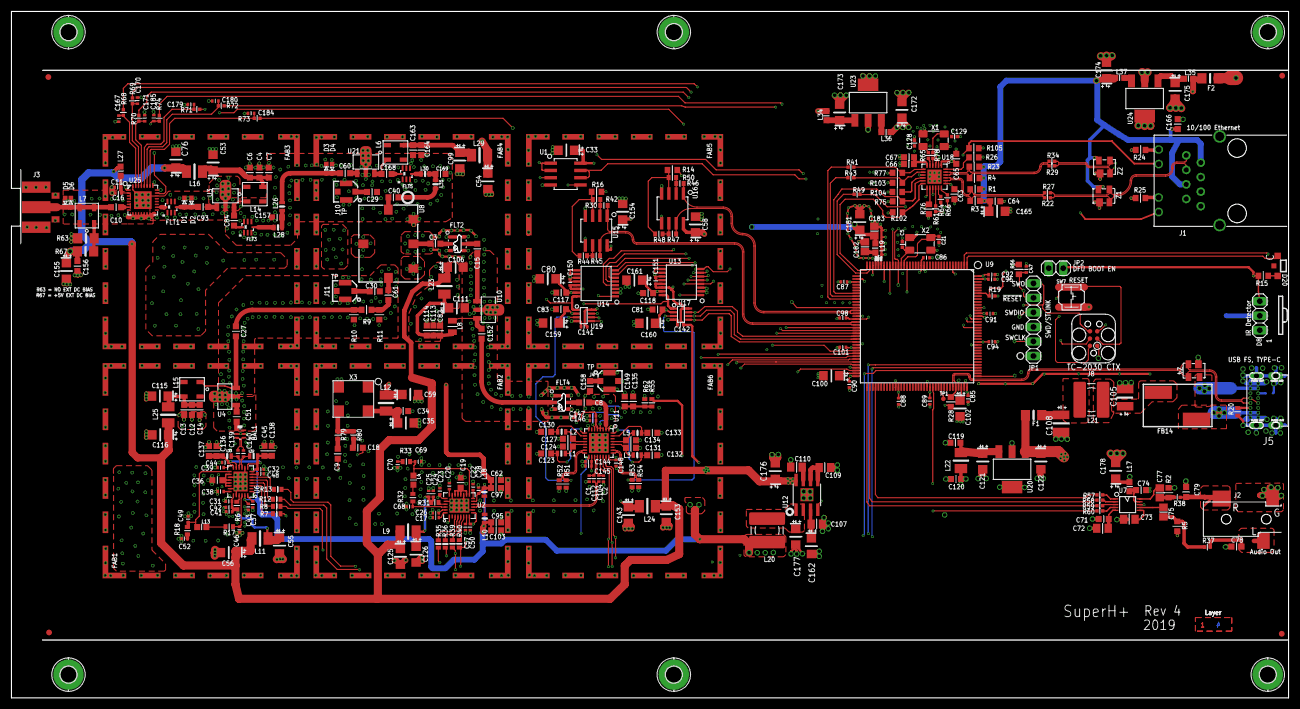
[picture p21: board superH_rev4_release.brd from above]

Board: 4 copper layers, 223.3 x 120.0 mm, 380 parts (1 on the bottom side), 228 nets.

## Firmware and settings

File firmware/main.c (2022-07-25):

//MIT License
//
//Copyright (c) 2019 tvelliott
//
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



#include <complex.h>
#include <math.h>

#include "globals.h"
#include "stm32h7xx_hal.h"
#include "lwip.h"
#include "mbelib_test_main.h"

#define ARM_MATH_CM7 1
#include "arm_common_tables.h"
#include "arm_math.h"



#include "p25_decode.h"
#include "p25_stats.h"

#include "channel_filter.h"

#include "fsk_decode_12.h"
#include "pocsag.h"

#include "telnet.h"

#include "lwip/udp.h"

#include "main.h"
#include "std_io.h"
#include "agc.h"
#include "freqsynth.h"
#include "rtl_tcp_driver.h"
#include "rfdemod.h"

#include "config.h"
#include "adsb_decoder.h"
#include "multimon.h"
#include "dmr_state.h"
#include "syncmon.h"

// These vectors need to be in address range that the DMA can access.
// See .ld file for definition of sections
// Also see MPU_Config().  Cache is disabled for these buffers so DMA works correctly
ALIGN_32BYTES( static uint32_t ADCBuffer[ADC_SIZE*2] __attribute__( ( section( ".ADCSection" ) ) ) ); //dual-mode interleaved ADC1 and ADC2, 8th-order BB filter, 2 channels, differential.
//ALIGN_32BYTES( static uint32_t ADCBuffer3[ADC_SIZE] __attribute__( ( section( ".ADC3Section" ) ) ) ); //regular conversion, 2.8 MHz BW, ADC3, 2-channels single-ended
ALIGN_32BYTES( volatile uint16_t   audio_tx[256] __attribute__( ( section( ".AudioSection" ) ) ) ); //I2S audio buffer


volatile int do_update_agc;
volatile int rssi_offset;
volatile int bb_gain;
static volatile int agc_update_mod;

uint32_t udp_send_ip_bak;

uint8_t *adc_ptr_half = ( ( uint8_t * ) &ADCBuffer[0] );
uint8_t *adc_ptr_full = ( ( uint8_t * ) &ADCBuffer[0] ) + ( ADC_SIZE * 4 ) / 2;

volatile int adc_idx = 0;
volatile float complex nco_buffer[1];

volatile float sweep[4096];
volatile double sweep_freq_start;
volatile double sweep_freq_stop;
volatile double sweep_step;
volatile int sweep_idx;
volatile float max;

static uint32_t telnet_tick_time;
extern volatile int8_t adc_ready;
volatile int adc_rate;
volatile int adc_count;
volatile int do_i2s;
volatile int is_playing;
volatile uint32_t out_s = 0;
volatile uint32_t out_e = 0;
volatile int alen;
volatile int do_sample_process = 1;

volatile int adc12_dma = 0;
volatile int adc3_dma = 0;

static volatile struct pbuf *p;
static volatile struct pbuf *pb;

static volatile int squelch_active = 1;
volatile int squelch_timer;

static volatile float angle1;
static volatile float angle2;

volatile struct ip4_addr udp_saddr;

volatile int do_freq_offset = 1;

volatile int do_48khz_iq_only = 0; //1==do RF IQ resamp from 100khz to 48khz only and send that over udp


volatile int channel_time;
volatile int channel_timeout;
volatile int tdu_count;
volatile int channel_settle;
volatile int stats_buffer_ready;
volatile int fft_buffer_ready;

volatile int did_print_channel;
static volatile float real_amp = 0.0f;

void p25_net_tick( void );
void process_incoming_samples( int16_t val );
void udp_send_data( uint8_t *buffer, int len );
void p25_udp_init( void );
void udp_data_rx( void *arg, struct udp_pcb *pcb, struct pbuf *p, struct ip4_addr *addr, uint16_t port );
int _mem_free( void );
void timer_tick( void );
void main_tick( void );

volatile uint32_t second_tick;
volatile uint32_t uptime_sec;
volatile int sample_cnt;
int found_signal;

volatile char in_buffer[1500 * IN_BUFFER_N];
volatile char in_buffer_tmp[1500 * IN_BUFFER_N];
volatile int in_buffer_len;

/* USER CODE BEGIN PV */
int64_t __errno;

volatile struct udp_pcb *udp_data_pcb;
int audio_frames_done;
int do_silent_frame;

/* USER CODE END PV */


ADC_HandleTypeDef hadc1;
ADC_HandleTypeDef hadc2;
ADC_HandleTypeDef hadc3;
I2S_HandleTypeDef hi2s2;
SPI_HandleTypeDef hspi3;
DMA_HandleTypeDef hdma_adc1;
DMA_HandleTypeDef hdma_adc2;
DMA_HandleTypeDef hdma_spi2_tx;
DMA_HandleTypeDef hdma_adc3;
ADC_HandleTypeDef hadc3;
TIM_HandleTypeDef htim2;
TIM_HandleTypeDef htim3;

static void SystemClock_Config( void );
static void MX_GPIO_Init( void );
static void MX_ADC1_Init( int oversample_rate, int clockdiv, int rightshift );
static void MX_ADC2_Init( int oversample_rate, int clockdiv, int rightshift );
static void MX_ADC3_Init( void );
static void MX_SPI3_Init( void );
static void MX_DMA_Init( void );
static void MX_I2S2_Init( void );
static void MX_TIM2_Init( void );
static void MX_TIM3_Init( void );

/* USER CODE BEGIN PFP */
void MPU_Config( void );
void tcp_iperf_init( void );
static volatile uint32_t current_time;
static uint32_t led_time;
static uint32_t p25_time;
static uint8_t led_state;
static uint32_t clk_mhz;

// initialize frame generator properties

/* USER CODE END PFP */

unsigned int did_sym = 0;

extern volatile int do_gqrx;
volatile int audio_out_rate;
volatile int audio_in_rate;

volatile struct pbuf *pb_adc; //not freed for speed when in ADSB mode
volatile struct pbuf *pb_audio; //not freed for audio_buffer output 
volatile int do_adsb_preamble;
volatile char adsb_buffer[ADC_SIZE*4*2];
volatile int  adsb_buffer_idx;
volatile int adsb_dc_offset;
int adsb_preamble_count;
volatile int adsb_overruns;

struct demod_state flexstate;

static volatile int16_t audio_buffer[512];
static volatile int ab_idx;

static volatile  uint32_t tmp_out_e;
static volatile  uint32_t tmp_out_s;
static volatile  float gain;
static volatile int do_vaudio;
///////////////////////////////////////////////////////////////////////////////////////////////
///////////////////////////////////////////////////////////////////////////////////////////////
int main( void )
{

  /* Reset of all peripherals, Initializes the Flash interface and the Systick. */
  HAL_Init();
  SystemClock_Config();

  HAL_Delay( 100 );

  //HAL_RCC_MCOConfig( RCC_MCO2, RCC_MCO2SOURCE_SYSCLK, RCC_MCODIV_8 );
  //delay_ms_ni(50);

  // activate SRAM1\2\3
  RCC->AHB2ENR |= ( 0x7 << 29 );

  MPU_Config();

  SCB_EnableICache();
  //SCB_DisableICache();

  /* USER CODE END 1 */

  /* Enable D-Cache-------------------------------------------------------------*/
  SCB_EnableDCache();
  //SCB_DisableDCache();

  /* MCU Configuration----------------------------------------------------------*/


  /* Initialize all configured peripherals */
  MX_SPI3_Init();
  MX_GPIO_Init();
  MX_DMA_Init();
  //MX_ADC1_Init(20,8,2);
  //MX_ADC2_Init(20,8,2);
  //MX_ADC3_Init();


  //TODO: FIX. disable ir remote related for now
  //MX_TIM2_Init();
  //MX_TIM3_Init();


  MX_GPIO_Init();
  HAL_GPIO_WritePin( synth1_cs_GPIO_Port, synth1_cs_Pin, GPIO_PIN_SET );
  HAL_GPIO_WritePin( synth2_cs_GPIO_Port, synth2_cs_Pin, GPIO_PIN_SET );
  HAL_GPIO_WritePin( mixer_cs_GPIO_Port, mixer_cs_Pin, GPIO_PIN_SET );

  leds_on();

  init_globals(); //this needs to be done before uart configuration  (baud rate) and networking configuration, etc


  rssi_offset = config->rssi_offset;
  bb_gain = config->gain1;

  MX_LWIP_Init();

  printf( "\r\n\r\nInstruction Cache Enabled" );
  printf( "\r\nData Cache Enabled" );
  printf( "\r\nHAL Initialized" );

  clk_mhz = SystemCoreClock / 1e6;
  printf( "\r\nSTM32H743 Running @ %lu MHz", clk_mhz );


  tcp_iperf_init();
  printf( "\r\niperf3 server started on port 5201" );



  adsb_init();
  p25_udp_init();
  init_dmr();
  telnet_init();
  rtl_tcp_driver_init();

  init_rfdemod();

  flex_init(&flexstate);

  int free = _mem_free();
  printf( "\r\nheap mem free %d bytes\r\n", free );

  init_dc_correction( ( double ) config->iq_dc_off_rate );


  HAL_GPIO_WritePin( rf_sw_GPIO_Port, rf_sw_Pin, GPIO_PIN_RESET );    //select RFB port while synths init
  set_atten( 63 ); //high front-end attenuation while synths init



  leds_on();
  HAL_Delay( 10 );
  init_synth2();
  HAL_Delay( 10 );
  init_synth1();
  HAL_Delay( 10 );
  init_mixer();
  HAL_Delay( 10 );
  leds_off();

  HAL_GPIO_WritePin( rf_sw_GPIO_Port, rf_sw_Pin, GPIO_PIN_SET );    //select RFA port

  MX_I2S2_Init();

  int i;
  for( i = 0; i < 256; i++ ) {
    //audio_tx[i] = (uint16_t) rand()%65535;
    audio_tx[i] = ( uint16_t ) 0;
  }


  sweep_freq_start = 900.0;
  sweep_freq_stop = 920.0;
  sweep_step = ( sweep_freq_stop - sweep_freq_start ) / ( float )( sizeof( sweep ) / 4 );
  //sweep_step= 0.020;

#if 0
  HAL_SYSCFG_VREFBUF_VoltageScalingConfig( SYSCFG_VREFBUF_VOLTAGE_SCALE0 );
  HAL_SYSCFG_EnableVREFBUF();
  HAL_SYSCFG_VREFBUF_HighImpedanceConfig( SYSCFG_VREFBUF_HIGH_IMPEDANCE_DISABLE );
#else
  HAL_SYSCFG_DisableVREFBUF();
  HAL_SYSCFG_VREFBUF_HighImpedanceConfig( SYSCFG_VREFBUF_HIGH_IMPEDANCE_ENABLE );
#endif

  __preset = 0;
  read_config();


  //HAL_TIM_Base_Start( &htim2 );

  start_eth_auto_neg();

  pb_adc = pbuf_alloc( PBUF_RAW, ADC_SIZE*4, PBUF_RAM );

  ////////////////////////////////////////////////////////////////////////////////////////////////////////////////////////
  //  main loop
  ////////////////////////////////////////////////////////////////////////////////////////////////////////////////////////
  while( 1 ) {


    timer_tick(); //timer related for P25

    int i;
    uint32_t prim;

    MX_LWIP_Process();

    main_tick();    //check various timers related to debug output, etc


    #if 1
    //move this to main loop outside of interrupt handler
    if(do_update_agc) {
      prim = __get_PRIMASK();
      __disable_irq();

      do_update_agc=0;

      if( !prim ) {
        __enable_irq();
      }

      //AGC function
      update_agc();
    }
    #endif
  }
}


//////////////////////////////////////////////////////////////////////////////////////////////////////
//////////////////////////////////////////////////////////////////////////////////////////////////////
void reconfig_adc( int channel_bw )
{
  uint32_t prim;
  RCC_PeriphCLKInitTypeDef PeriphClkInitStruct = {0};



  if( adc12_dma ) {
    HAL_ADCEx_MultiModeStop_DMA( &hadc1 );
    delay_ms_ni( 1 );
    adc12_dma = 0;
    HAL_ADC_DeInit( &hadc1 );
    HAL_ADC_DeInit( &hadc2 );
  }
  if( adc3_dma ) {
    HAL_ADC_Stop_DMA( &hadc3 );
    delay_ms_ni( 1 );
    adc3_dma = 0;
    HAL_ADC_DeInit( &hadc3 );
  }

  delay_ms_ni( 1 );

  prim = __get_PRIMASK();
  __disable_irq();

  config->channel_bw = channel_bw;

    PeriphClkInitStruct.PeriphClockSelection = RCC_PERIPHCLK_SPI3|RCC_PERIPHCLK_SPI2
                                |RCC_PERIPHCLK_ADC;
    PeriphClkInitStruct.PLL2.PLL2M = 2;
    PeriphClkInitStruct.PLL2.PLL2N = 157;
    PeriphClkInitStruct.PLL2.PLL2P = 4;
    PeriphClkInitStruct.PLL2.PLL2Q = 2;
    PeriphClkInitStruct.PLL2.PLL2R = 2;
    PeriphClkInitStruct.PLL2.PLL2RGE = RCC_PLL2VCIRANGE_2;
    PeriphClkInitStruct.PLL2.PLL2VCOSEL = RCC_PLL2VCOWIDE;
    PeriphClkInitStruct.PLL2.PLL2FRACN = 1840;
    PeriphClkInitStruct.PLL3.PLL3M = 1;
    PeriphClkInitStruct.PLL3.PLL3N = 19;
    PeriphClkInitStruct.PLL3.PLL3P = 2;
    PeriphClkInitStruct.PLL3.PLL3Q = 2;
    PeriphClkInitStruct.PLL3.PLL3R = 2;
    PeriphClkInitStruct.PLL3.PLL3RGE = RCC_PLL3VCIRANGE_3;
    PeriphClkInitStruct.PLL3.PLL3VCOSEL = RCC_PLL3VCOMEDIUM;

  switch( config->sa_mode ) {

  case  MODE_ADSB :

    PeriphClkInitStruct.PLL3.PLL3N = 22;
    PeriphClkInitStruct.PLL3.PLL3FRACN = config->adc3_frac;    //2MSPS in sa_mode==5 mode  (ADSB)
    PeriphClkInitStruct.Spi123ClockSelection = RCC_SPI123CLKSOURCE_PLL2;
    PeriphClkInitStruct.AdcClockSelection = RCC_ADCCLKSOURCE_PLL3;
    if (HAL_RCCEx_PeriphCLKConfig(&PeriphClkInitStruct) != HAL_OK)
    {
      _Error_Handler( __FILE__, __LINE__ );
    }
    MX_ADC3_Init();

    mixer_write_reg( 0x0e, 4 ); //I dc offset, leave at 1 for best sensitivity
    mixer_write_reg( 0x0f, 4 ); //Q dc offset, leave at 1 for best sensitivity

    HAL_ADC_Start_DMA( &hadc3, ( uint32_t * ) ADCBuffer, ADC_SIZE * 8 ); //ADC3  regular conversion 2 channels, single-ended
    adc3_dma = 1;
    break;

  case  MODE_FM :
  case  MODE_IQ :
  case  MODE_P25 :
  case  MODE_SYNCMON :
  case  MODE_AM :
  case  MODE_4 :
  case  MODE_6 :
  case  MODE_DMR :
  default :

    PeriphClkInitStruct.PLL3.PLL3N = 19;
    PeriphClkInitStruct.PLL3.PLL3FRACN = 1484;  //800ksps in channel_bw=1 mode
    PeriphClkInitStruct.Spi123ClockSelection = RCC_SPI123CLKSOURCE_PLL2;
    PeriphClkInitStruct.AdcClockSelection = RCC_ADCCLKSOURCE_PLL3;
    if (HAL_RCCEx_PeriphCLKConfig(&PeriphClkInitStruct) != HAL_OK)
    {
      _Error_Handler( __FILE__, __LINE__ );
    }
    switch( config->channel_bw ) {
    case  0 : //narrow
      MX_ADC1_Init( 16, 8, 2 ); //oversample=20, clockdiv=8, righshift=2
      MX_ADC2_Init( 16, 8, 2 );
      //set_bw( 1 ); // +/- 10kHz
      break;

    case  1 : //wide
      MX_ADC1_Init( 3, 4, 1 ); //oversample=2, clockdiv=4, righshift=1
      MX_ADC2_Init( 3, 4, 1 );
      //set_bw( 9 ); // +/- 90 kHz
      break;

    case  2 : //medium
      MX_ADC1_Init( 12, 4, 1 ); //oversample=12, clockdiv=4, righshift=1
      MX_ADC2_Init( 12, 4, 1 );
      //set_bw( 2 ); // +/- 20kHz
      break;
    }

    mixer_write_reg( 0x0e, (uint8_t) config->mixer_doi ); //I dc offset, leave at 1 for best sensitivity
    mixer_write_reg( 0x0f, (uint8_t) config->mixer_doq ); //Q dc offset, leave at 1 for best sensitivity

    HAL_ADCEx_MultiModeStart_DMA( &hadc1, ( uint32_t * ) ADCBuffer, ADC_SIZE ); //ADC1 and ADC2 interleaved, 2 channels, differential-ended
    adc12_dma = 1;
    break;
  }


  out_s = 0;
  out_e = 0;
  is_playing = 0;   //allow some audio to buffer back up again
  udp_out_len = 0;

  if( !prim ) {
    __enable_irq();
  }

  set_freq_mhz( config->frequency + config->if_frequency ); //reset freq because do_low_if_mix might have changed
}

//////////////////////////////////////////////////////////////////////////////////////////////////////
//////////////////////////////////////////////////////////////////////////////////////////////////////
void check_udp_out()
{
  uint32_t prim;
  uint8_t buffer[1514];
  int len=0;

  MX_LWIP_Process();

  switch( config->sa_mode ) {
  case  MODE_P25 :
  case  MODE_DMR :
  case  MODE_SYNCMON :
  case  MODE_FM :
  case  MODE_AM :

    if( config->udp_mode==UDP_STREAM_DEMOD && udp_out_len%2==0 && udp_out_len>=64 ) { 
      prim = __get_PRIMASK();
      __disable_irq();
      len = udp_out_len;
      goto len_gtz;
    }
    else if( config->udp_mode==UDP_STREAM_IQ16_DECFLT && udp_out_len > 255 && udp_out_len%2==0) { 
      prim = __get_PRIMASK();
      __disable_irq();
      len = udp_out_len;
      goto len_gtz;
    }
      //else if( config->udp_mode==UDP_STREAM_IQ16_DECFLT && udp_out_len == ((ADC_SIZE/2)/config->decimate)*8 ) { 
       // len = udp_out_len;
      //}

    if(len>0) {
len_gtz:
      if(len>1460) len=1460;
      if(len<=0) goto len_isz;

      pb = pbuf_alloc( PBUF_RAW, len, PBUF_RAM );
      if( pb != NULL ) {
        memcpy( pb->payload, ( uint8_t * ) udp_out_buffer, len );
        memcpy( buffer, ( uint8_t * ) udp_out_buffer, len );

        udp_sendto( udp_data_pcb, pb, &udp_saddr, UDP_PORT );

        if(pb) pbuf_free( pb );
      }

len_isz:
      udp_out_len = 0;

      if( !prim ) {
        __enable_irq();
      }

      //run decoders if enabled
      if( !squelch_active && len > 0 && config->udp_mode==UDP_STREAM_DEMOD) {
        if( config->do_pagers ) {
          pocsag_12_decode( ( int16_t * ) &buffer[0], len / 2 );
          flex_demod(&flexstate, ( int16_t * ) &buffer[0], len / 2);
        }
        if(config->do_acars) {
          acars_decode(&buffer[0], len/2);
        }
      }

    }

    break;

  case MODE_IQ  :
    if( udp_out_len == ( ADC_SIZE * 4 ) / config->decimate ) {

      prim = __get_PRIMASK();
      __disable_irq();

      if(udp_out_len>1460) udp_out_len=1460;

      pb = pbuf_alloc( PBUF_RAW, udp_out_len, PBUF_RAM );
      if( pb != NULL ) {
        memcpy( pb->payload, ( uint8_t * ) udp_out_buffer, udp_out_len );
        udp_sendto( udp_data_pcb, pb, &udp_saddr, UDP_PORT );
        udp_out_len = 0;
        if(pb) pbuf_free( pb );
      }

      if( !prim ) {
        __enable_irq();
      }

    }

  case MODE_4  :
    if( udp_out_len == ( ADC_SIZE * 4 ) ) {

      prim = __get_PRIMASK();
      __disable_irq();
      if(udp_out_len>1460) udp_out_len=1460;

      pb = pbuf_alloc( PBUF_RAW, udp_out_len, PBUF_RAM );
      if( pb != NULL ) {
        memcpy( pb->payload, ( uint8_t * ) udp_out_buffer, udp_out_len );
        udp_sendto( udp_data_pcb, pb, &udp_saddr, UDP_PORT );
        udp_out_len = 0;
        if(pb) pbuf_free( pb );
      }

      if( !prim ) {
        __enable_irq();
      }

    }
    break;
  }


  if( config->sa_mode!=MODE_P25 && config->sa_mode!=MODE_DMR && 
                     ab_idx>256  && (config->udp_mode==UDP_STREAM_AUDIO_48K_S16 ||
                     config->udp_mode==UDP_STREAM_AUDIO_48K_S16_CONT) ) {
    prim = __get_PRIMASK();
    __disable_irq();

    len = ab_idx*2;
    if( config->udp_mode!=UDP_STREAM_AUDIO_48K_S16_CONT && squelch_active) {
      len = 0;
    }

    if(len>0) {
      if(len>1460) len=1460;
      //audio buffer pbuf 
      pb_audio = pbuf_alloc( PBUF_RAW, len , PBUF_RAM );

      if(pb_audio!=NULL) {
        memcpy( pb_audio->payload, ( uint8_t * ) audio_buffer , len );
        udp_sendto( udp_data_pcb, pb_audio, &udp_saddr, UDP_PORT );
        if(pb_audio ) pbuf_free(pb_audio);
      }
    }

    ab_idx=0;
    if( !prim ) {
      __enable_irq();
    }
  }
}


//////////////////////////////////////////////////////////////////////////////////////////////////////
//////////////////////////////////////////////////////////////////////////////////////////////////////
void led1_on( void )
{
  HAL_GPIO_WritePin( LED1_GPIO_Port, LED1_Pin, GPIO_PIN_RESET );
}
//////////////////////////////////////////////////////////////////////////////////////////////////////
//////////////////////////////////////////////////////////////////////////////////////////////////////
void led1_off( void )
{
  HAL_GPIO_WritePin( LED1_GPIO_Port, LED1_Pin, GPIO_PIN_SET );
}
//////////////////////////////////////////////////////////////////////////////////////////////////////
//////////////////////////////////////////////////////////////////////////////////////////////////////
void led2_on( void )
{
  HAL_GPIO_WritePin( LED2_GPIO_Port, LED2_Pin, GPIO_PIN_RESET );
}
//////////////////////////////////////////////////////////////////////////////////////////////////////
//////////////////////////////////////////////////////////////////////////////////////////////////////
void led2_off( void )
{
  HAL_GPIO_WritePin( LED2_GPIO_Port, LED2_Pin, GPIO_PIN_SET );
}



//////////////////////////////////////////////////////////////////////////////////////////////////////
//////////////////////////////////////////////////////////////////////////////////////////////////////
void leds_on( void )
{
  HAL_GPIO_WritePin( LED1_GPIO_Port, LED1_Pin, GPIO_PIN_RESET );
  HAL_GPIO_WritePin( LED2_GPIO_Port, LED2_Pin, GPIO_PIN_RESET );
}
//////////////////////////////////////////////////////////////////////////////////////////////////////
//////////////////////////////////////////////////////////////////////////////////////////////////////
void leds_off( void )
{
  HAL_GPIO_WritePin( LED1_GPIO_Port, LED1_Pin, GPIO_PIN_SET );
  HAL_GPIO_WritePin( LED2_GPIO_Port, LED2_Pin, GPIO_PIN_SET );
}
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

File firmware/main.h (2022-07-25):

//MIT License
//
//Copyright (c) 2019 tvelliott
//
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


#ifndef __MAIN_H__
#define __MAIN_H__

#include "stm32h7xx_hal.h"

#define ARM_MATH_CM7 1
#include "arm_common_tables.h"
#include "arm_math.h"

#define IN_BUFFER_N 16
#define N_SAMPLES 256

extern volatile int do_sample_process;
extern volatile int rssi_offset;
extern volatile int bb_gain;
extern volatile int fft_buffer_ready;
extern volatile int adc_rate;
extern volatile int stats_buffer_ready;
extern volatile int channel_settle;
extern volatile int squelch_timer;
extern volatile double d_alpha_i;
extern volatile double d_alpha_q;
extern volatile double d_beta_i;
extern volatile double d_beta_q;
void reset_channel_timeout( void );
void set_channel_timeout_zero( void );
void set_channel_timeout_min( void );
void scanner_next_channel( void );
double get_current_freq( void );
void process_incoming_rf( void );
int upsample_audio( uint8_t *buffer, int len );
void _Error_Handler( char *file, int line );
void calc_stddev( int16_t *data, int n );
int main( void );
float atan2f( float y, float x );
float get_real_amp( void );
extern volatile int udp_out_len;
extern float eqlms_dhat[1];
extern float eqlms_d[1];
extern float eqlms_mu;
extern float eqlms_beta;
extern unsigned int eqlms_m;
extern unsigned int eqlms_k;
extern struct eqlms_rf_s *eqlms;
extern struct freqmod_s *freqmod;
extern struct nco_cf_s *nco;
extern volatile int upsample_ready;
extern volatile short upsampled[160 * 6];
extern struct resamp_rf_s *audio_resamp_q;
extern unsigned int audio_resamp_npfb;
extern float audio_resamp_bw;
extern float audio_resamp_As;
extern unsigned int audio_resamp_m;
extern float audio_resamp_r;
extern unsigned int ch_ny;
extern struct resamp2_s *halfband_q;
extern float half_band_as;
extern unsigned int half_band_m;
extern struct resamp_cf_s *ch_resamp_q;
extern unsigned int ch_resamp_npfb;
extern float ch_resamp_bw;
extern float ch_resamp_As;
extern unsigned int ch_resamp_m;
extern float ch_resamp_r;
extern struct symsync_s *q;
extern struct symsync_s symsync;
extern float symsync_buf_out[1];
extern float symsync_buf_in[1];
extern unsigned int symsync_npfb;
extern float symsync_beta;
extern unsigned int symsync_m;
extern unsigned int symsync_k;
extern int symsync_ftype;
extern unsigned int did_sym;
void tcp_iperf_init( void );
static void MX_SPI3_Init( void );
static void SystemClock_Config( void );
extern volatile int fm_cnt;
extern int eqlms_trained;
extern int do_silent_frame;
extern int audio_frames_done;
extern volatile struct udp_pcb *udp_data_pcb;
extern int64_t __errno;
extern volatile int scanner_mod;
extern volatile int in_buffer_len;
extern volatile char in_buffer_tmp[1500 * IN_BUFFER_N];
extern volatile char in_buffer[1500 * IN_BUFFER_N];
extern int found_signal;
extern volatile int sample_cnt;
extern volatile uint32_t uptime_sec;
extern volatile uint32_t second_tick;
void main_tick( void );
void main_tick();
void led_tick( void );
void led_tick();
int _mem_free( void );
void udp_data_rx( void *arg, struct udp_pcb *pcb, struct pbuf *p, struct ip4_addr *addr, uint16_t port );
void p25_udp_init( void );
void p25_udp_init();
void udp_send_data( uint8_t *buffer, int len );
void udp_send_data( uint8_t *buffer, int len );
void process_incoming_samples( int16_t val );
void process_incoming_samples( int16_t val );
void p25_net_tick( void );
extern SPI_HandleTypeDef hspi3;
extern ADC_HandleTypeDef hadc3;
extern ADC_HandleTypeDef hadc2;
extern ADC_HandleTypeDef hadc1;
extern volatile int did_print_channel;
extern volatile double scanner_freq_p25[];
extern volatile int scanner_channel_mask[];
extern volatile int scanner_freqs;
extern volatile int8_t std_dev;
extern volatile uint32_t scanner_idle_time;
extern volatile int scanner_channel;
extern volatile int channel_timeout;
extern int stddev_n;
extern float32_t stddev_out;
extern float32_t stddev_in[N_SAMPLES];
extern volatile int do_low_if_mix;
extern volatile int do_48khz_iq_only;
extern volatile int do_freq_offset;
extern volatile struct ip4_addr udp_saddr;
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

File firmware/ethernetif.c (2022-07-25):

/**
  ******************************************************************************
  * File Name          : ethernetif.c
  * Description        : This file provides code for the configuration
  *                      of the ethernetif.c MiddleWare.
  ******************************************************************************
  * This notice applies to any and all portions of this file
  * that are not between comment pairs USER CODE BEGIN and
  * USER CODE END. Other portions of this file, whether
  * inserted by the user or by software development tools
  * are owned by their respective copyright owners.
  *
  * Copyright (c) 2018 STMicroelectronics International N.V.
  * All rights reserved.
  *
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
  ******************************************************************************
  */

/* Includes ------------------------------------------------------------------*/
#include "stm32h7xx_hal.h"
#include "lwip/opt.h"
#include "lwip/mem.h"
#include "lwip/memp.h"
#include "lwip/timeouts.h"
#include "netif/ethernet.h"
#include "netif/etharp.h"
#include "lwip/ethip6.h"
#include "ethernetif.h"
#include "lan8742.h"
#include <string.h>

#include "globals.h"

/* Within 'USER CODE' section, code will be kept by default at each generation */

/* Network interface name */
#define IFNAME0 's'
#define IFNAME1 't'

extern struct netif gnetif;
/* USER CODE BEGIN 1 */

int8_t eth_low_level_initialized;

//NOTE: DMA Descriptors and LwIP TX buffers must be configured to use the MPU.
//      See MPU_Config() in main.c
//
/* USER CODE END 1 */

/*
@Note: This interface is implemented to operate in zero-copy mode only:
        - Rx buffers are allocated statically and passed directly to the LwIP stack
          they will return back to DMA after been processed by the stack.
        - Tx Buffers will be allocated from LwIP stack memory heap,
          then passed to ETH HAL driver.

@Notes:
  1.a. ETH DMA Rx descriptors must be contiguous, the default count is 4,
       to customize it please redefine ETH_RX_DESC_CNT in ETH GUI (Rx Descriptor Length)
       so that updated value will be generated in stm32xxxx_hal_conf.h
  1.b. ETH DMA Tx descriptors must be contiguous, the default count is 4,
       to customize it please redefine ETH_TX_DESC_CNT in ETH GUI (Tx Descriptor Length)
       so that updated value will be generated in stm32xxxx_hal_conf.h

  2.a. Rx Buffers number must be between ETH_RX_DESC_CNT and 2*ETH_RX_DESC_CNT
  2.b. Rx Buffers must have the same size: ETH_MAX_PACKET_SIZE, this value must
       passed to ETH DMA in the init field (heth.Init.RxBuffLen)
*/

ETH_DMADescTypeDef DMARxDscrTab[ETH_RX_DESC_CNT] __attribute__( ( section( ".RxDecripSection" ) ) ); /* Ethernet Rx DMA Descriptors */
ETH_DMADescTypeDef DMATxDscrTab[ETH_TX_DESC_CNT] __attribute__( ( section( ".TxDecripSection" ) ) ); /* Ethernet Tx DMA Descriptors */
uint8_t Rx_Buff[ETH_RX_DESC_CNT][ETH_MAX_PACKET_SIZE] __attribute__( ( section( ".RxArraySection" ) ) ); /* Ethernet Receive Buffers */

uint32_t current_pbuf_idx = 0;

/* Global Ethernet handle */
ETH_HandleTypeDef heth;
ETH_TxPacketConfig TxConfig;
struct pbuf_custom rx_pbuf[ETH_RX_DESC_CNT];

int32_t ETH_PHY_IO_Init( void );
int32_t ETH_PHY_IO_DeInit( void );
int32_t ETH_PHY_IO_ReadReg( uint32_t DevAddr, uint32_t RegAddr, uint32_t *pRegVal );
int32_t ETH_PHY_IO_WriteReg( uint32_t DevAddr, uint32_t RegAddr, uint32_t RegVal );
int32_t ETH_PHY_IO_GetTick( void );

lan8742_Object_t LAN8742;
lan8742_IOCtx_t  LAN8742_IOCtx = {ETH_PHY_IO_Init,
                                  ETH_PHY_IO_DeInit,
                                  ETH_PHY_IO_WriteReg,
                                  ETH_PHY_IO_ReadReg,
                                  ETH_PHY_IO_GetTick
                                 };

void pbuf_free_custom( struct pbuf *p );

void start_eth_auto_neg( void )
{
  LAN8742_StartAutoNego( &LAN8742 );
}

void HAL_ETH_MspInit( ETH_HandleTypeDef *ethHandle )
{
  GPIO_InitTypeDef GPIO_InitStruct;
  if( ethHandle->Instance == ETH ) {
    /* Enable Peripheral clock */
    __HAL_RCC_ETH1MAC_CLK_ENABLE();
    __HAL_RCC_ETH1TX_CLK_ENABLE();
    __HAL_RCC_ETH1RX_CLK_ENABLE();

    /**ETH GPIO Configuration
    PC1     ------> ETH_MDC
    PA1     ------> ETH_REF_CLK
    PA2     ------> ETH_MDIO
    PA7     ------> ETH_CRS_DV
    PC4     ------> ETH_RXD0
    PC5     ------> ETH_RXD1
    PG14     ------> ETH_TXD1
    PG11     ------> ETH_TX_EN
    PG13     ------> ETH_TXD0
    */
    GPIO_InitStruct.Pin = GPIO_PIN_1 | GPIO_PIN_4 | GPIO_PIN_5;
    GPIO_InitStruct.Mode = GPIO_MODE_AF_PP;
    GPIO_InitStruct.Pull = GPIO_PULLUP;
    GPIO_InitStruct.Speed = GPIO_SPEED_FREQ_HIGH;
    GPIO_InitStruct.Alternate = GPIO_AF11_ETH;
    HAL_GPIO_Init( GPIOC, &GPIO_InitStruct );

    GPIO_InitStruct.Pin = GPIO_PIN_1 | GPIO_PIN_2 | GPIO_PIN_7;
    GPIO_InitStruct.Mode = GPIO_MODE_AF_PP;
    GPIO_InitStruct.Pull = GPIO_NOPULL;
    GPIO_InitStruct.Speed = GPIO_SPEED_FREQ_HIGH;
    GPIO_InitStruct.Alternate = GPIO_AF11_ETH;
    HAL_GPIO_Init( GPIOA, &GPIO_InitStruct );

    GPIO_InitStruct.Pin = GPIO_PIN_11 | GPIO_PIN_13 | GPIO_PIN_14;
    GPIO_InitStruct.Mode = GPIO_MODE_AF_PP;
    GPIO_InitStruct.Pull = GPIO_NOPULL;
    GPIO_InitStruct.Speed = GPIO_SPEED_FREQ_HIGH;
    GPIO_InitStruct.Alternate = GPIO_AF11_ETH;
    HAL_GPIO_Init( GPIOG, &GPIO_InitStruct );


  }
}

void HAL_ETH_MspDeInit( ETH_HandleTypeDef *ethHandle )
{
  if( ethHandle->Instance == ETH ) {
    /* Disable Peripheral clock */
    __HAL_RCC_ETH1MAC_CLK_DISABLE();
    __HAL_RCC_ETH1TX_CLK_DISABLE();
    __HAL_RCC_ETH1RX_CLK_DISABLE();

    /**ETH GPIO Configuration
    PC1     ------> ETH_MDC
    PA1     ------> ETH_REF_CLK
    PA2     ------> ETH_MDIO
    PA7     ------> ETH_CRS_DV
    PC4     ------> ETH_RXD0
    PC5     ------> ETH_RXD1
    PG14     ------> ETH_TXD1
    PG11     ------> ETH_TX_EN
    PG13     ------> ETH_TXD0
    */
    HAL_GPIO_DeInit( GPIOC, GPIO_PIN_1 | GPIO_PIN_4 | GPIO_PIN_5 );

    HAL_GPIO_DeInit( GPIOA, GPIO_PIN_1 | GPIO_PIN_2 | GPIO_PIN_7 );

    HAL_GPIO_DeInit( GPIOG, GPIO_PIN_11 | GPIO_PIN_13 | GPIO_PIN_14 );


  }
}
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

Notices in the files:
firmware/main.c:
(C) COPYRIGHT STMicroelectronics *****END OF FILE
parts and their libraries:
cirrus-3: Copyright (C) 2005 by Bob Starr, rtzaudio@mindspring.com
